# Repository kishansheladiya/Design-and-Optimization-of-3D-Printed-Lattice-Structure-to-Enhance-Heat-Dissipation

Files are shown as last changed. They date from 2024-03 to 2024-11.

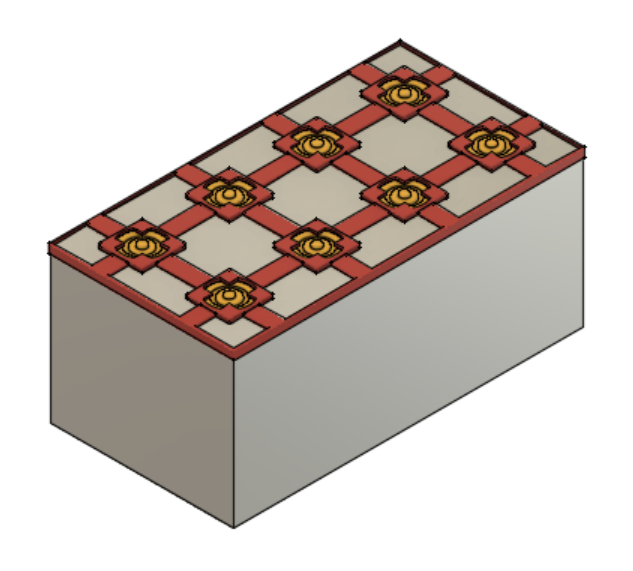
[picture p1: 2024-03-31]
model idea.PNG

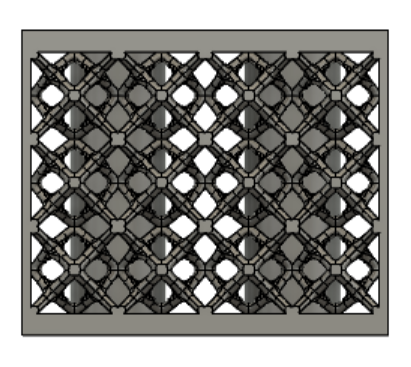
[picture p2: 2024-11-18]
Unitcell/Dedecahedron/front.PNG

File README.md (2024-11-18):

# **Design and Optimization of 3D Printed Lattice Structure to Enhance Heat Dissipation**

This project explores the design and optimization of 3D-printed lattice structures to improve heat dissipation for thermal management applications. Using advanced simulation techniques and CAD modeling, the project demonstrates how lattice geometries can enhance thermal efficiency in various engineering systems.

---

## 📌 **Objectives**
- Design and analyze various lattice structures for enhanced heat transfer.
- Optimize the design to maximize cooling performance while maintaining structural integrity.
- Use additive manufacturing techniques to implement and test designs.

---

## 🔧 **Tools & Technologies Used**
- **Simulation Software**: ANSYS Fluent for thermal analysis.
- **CAD Software**: Fusion 360, Rhino Grasshopper for lattice design.
- **Programming**: Python for data analysis and parameter optimization.

---

## 🛠️ **Methodology**

### **Lattice Design**:
- Designed different lattice structures (e.g., Tricut, BC star tetrahedron) using Rhino Grasshopper and Fusion 360.
- Optimized porosity and surface area for heat transfer performance.

### **Simulation**:
- Conducted structural analysis to ensure load-bearing capability.
- Performed heat transfer simulations using ANSYS Fluent.

### **Optimization**:
- Compared thermal and structural performance of different lattice geometries.

---

## 📊 **Results**

### **Key Findings**:
- Tricut lattice structure exhibited the best cooling performance with a heat transfer value of **1888.80 J/s**.
- Achieved **27% improvement** in heat dissipation compared to baseline designs.

### **Visuals**:
- Example: Temperature contour for Tricut lattice structure.

---

## 🚀 **Applications**
- Battery Thermal Management Systems.
- Heat Sinks and Exchangers.
- Additive Manufacturing for Advanced Cooling Designs.

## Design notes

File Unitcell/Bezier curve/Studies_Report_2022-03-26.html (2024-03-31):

Image Width (pixels):

# Study Report

Analyzed File | bezier curve R 1.2 new result v1
Version | Autodesk Fusion 360 (2.0.12392)
Creation Date | 2022-03-26, 20:36:04
Author | 18BME0245 kishan

#### Project Properties

Title | Studies
Author | K_K_Sheladiya

## Simulation Model 1:1

### Study 1 - Static Stress

##### Study Properties

Study Type | Static Stress
Last Modification Date | 2022-03-26, 17:51:15

#### Settings

##### General

Contact Tolerance | 0.1 mm
Remove Rigid Body Modes | No

##### Damping

##### Mesh

Average Element Size (% of model size)
Solids | 10
Scale Mesh Size Per Part | No
Average Element Size (absolute value) | -
Element Order | Parabolic
Create Curved Mesh Elements | Yes
Max. Turn Angle on Curves (Deg.) | 60
Max. Adjacent Mesh Size Ratio | 1.5
Max. Aspect Ratio | 10
Minimum Element Size (% of average size) | 20

##### Adaptive Mesh Refinement

Number of Refinement Steps | 0
Results Convergence Tolerance (%) | 20
Portion of Elements to Refine (%) | 10
Results for Baseline Accuracy | Von Mises Stress

#### Materials

Component | Material | Safety Factor
Body1 | Aluminum | Yield Strength

##### Aluminum

Density | 2.715E-06 kg / mm^3
Young's Modulus | 71000 MPa
Poisson's Ratio | 0.33
Yield Strength | 85 MPa
Ultimate Tensile Strength | 120 MPa
Thermal Conductivity | 0.222 W / (mm C)
Thermal Expansion Coefficient | 2.4E-05 / C
Specific Heat | 900 J / (kg C)

#### Contacts

#### Mesh

Type | Nodes | Elements
Solids | 706362 | 402637

#### Load Case1

#### Constraints

##### Fixed1

Type | Fixed
Ux | Fixed
Uy | Fixed
Uz | Fixed

###### Selected Entities

For correct interpretation of this image use e.g. IE9, Chrome, Safari, Firefox

#### Loads

##### Force1

Type | Force
Magnitude | 40 N
X Value | 0 N
Y Value | 0 N
Z Value | -40 N
Force Per Entity | No

###### Selected Entities

For correct interpretation of this image use e.g. IE9, Chrome, Safari, Firefox

#### Results

##### Result Summary

Name | Minimum | Maximum
Safety Factor
Safety Factor (Per Body) | 15 | 15
Stress
Von Mises | 2.764E-05 MPa | 0.09797 MPa
1st Principal | -0.04335 MPa | 0.07597 MPa
3rd Principal | -0.1365 MPa | 0.01963 MPa
Normal XX | -0.0581 MPa | 0.06591 MPa
Normal YY | -0.07247 MPa | 0.069 MPa
Normal ZZ | -0.1129 MPa | 0.03409 MPa
Shear XY | -0.02942 MPa | 0.0299 MPa
Shear YZ | -0.03769 MPa | 0.0329 MPa
Shear ZX | -0.03552 MPa | 0.03509 MPa
Displacement
Total | 0 mm | 5.255E-05 mm
X | -1.219E-05 mm | 1.216E-05 mm
Y | -9.805E-06 mm | 9.818E-06 mm
Z | -5.197E-05 mm | 4.024E-07 mm
Reaction Force
Total | 0 N | 0.1304 N
X | -0.04135 N | 0.04227 N
Y | -0.03502 N | 0.03791 N
Z | -0.02533 N | 0.1275 N
Strain
Equivalent | 6.605E-10 | 2.201E-06
1st Principal | -5.492E-08 | 1.462E-06
3rd Principal | -2.404E-06 | 6.831E-09
Normal XX | -5.843E-07 | 8.032E-07
Normal YY | -6.644E-07 | 8.503E-07
Normal ZZ | -1.26E-06 | 3.355E-07
Shear XY | -1.102E-06 | 1.12E-06
Shear YZ | -1.412E-06 | 1.233E-06
Shear ZX | -1.331E-06 | 1.315E-06

##### Safety Factor

###### Safety Factor (Per Body)

0 8

For correct interpretation of this image use e.g. IE9, Chrome, Safari, Firefox

##### Stress

###### Von Mises

[MPa] 0.00003 0.09797

For correct interpretation of this image use e.g. IE9, Chrome, Safari, Firefox

###### 1st Principal

[MPa] -0.04335 0.07597

For correct interpretation of this image use e.g. IE9, Chrome, Safari, Firefox

###### 3rd Principal

[MPa] -0.1365 0.0196

For correct interpretation of this image use e.g. IE9, Chrome, Safari, Firefox

##### Displacement

###### Total

[mm] 0 5.255E-05

For correct interpretation of this image use e.g. IE9, Chrome, Safari, Firefox

Image Width (pixels):

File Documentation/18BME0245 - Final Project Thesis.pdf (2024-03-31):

## DESIGN AND OPTIMIZATION OF 3D PRINTED

## LATTICE STRUCTURE TO ENHANCE HEAT

## DISSIPATION

A PROJECT REPORT

### Submitted in partial fulfillment for the award of the degree of

## Bachelor of Technology

in

## Mechanical Engineering

by

PATEL RUTVIKKUMAR VINAYBHAI - | 18BME0059
SHELADIYA KISHAN KANTIBHAI | - | 18BME0245
SOJITRA DIPTESH MUKESHBHAI | - | 18BME2056

## School of Mechanical Engineering

## April, 2022

DECLARATION BY THE CANDIDATE

### I hereby declare that the project report entitled “DESIGN AND

OPTIMIZATION OF 3D PRINTED LATTICE STRUCTURE TO

### ENHANCE HEAT DISSIPATION” submitted by me to Vellore Institute of

### Technology University, Vellore in partial fulfillment of the requirement for the

award of the degree of Bachelor of Technology in Mechanical Engineering

### is a record of bonafide project work carried out by me under the supervision of

### Prof. Ranjeet Kumar. I declare that this report represents my concepts written

### in my own words and where others' ideas or words have been included, I have

### adequately cited and referenced the original sources. I further declare that I

### have adhered to all principles of academic honesty and integrity and have not

### misrepresented or fabricated or falsified any idea/data/fact/source in my

### submission. I understand that any violation of the above will be cause for

### disciplinary action by the Institute and can also evoke penal action from the

### sources which have thus not been properly cited or from whom proper

### permission has not been taken when needed. Further I affirm that the contents

### of this report have not been submitted and will not be submitted either in part

or in full, for the award of any other degree or diploma and the same is certified.

### Place: Vellore Date: 26/04/2022

SOJITRA DIPTESH MUKESHBHAI

PATEL RUTVIKKUMAR VINAYBHAI | SHELADIYA KISHAN KANTIBHAI

## School of Mechanical Engineering

## BONAFIDE CERTIFICATE

### This is to certify that the project report entitled “DESIGN AND

OPTIMIZATION OF 3D PRINTED LATTICE STRUCTURE TO

ENHANCE HEAT DISSIPATION” submitted by SHELADIYA KISHAN

KANTIBHAI (18BME0245) to Vellore Institute of Technology University,

### Vellore, in partial fulfillment of the requirement for the award of the degree of

Bachelor of Technology in Mechanical Engineering is a record of bonafide

### work carried out by him/her under my guidance. The project fulfills the

### requirements as per the regulations of this institute and in my opinion meets the

### necessary standards for submission. The contents of this report have not been

### submitted and will not be submitted either in part or in full, for the award of

any other degree or diploma and the same is certified.

Project Guide | Head of the Department
Internal Examiner | External Examiner

ACKNOWLEDGEMENT

I express my profound gratitude to my project Guide Dr. Ranjeet Kumar,

Associate Professor Sr Grade 1, School of Mechanical Engineering, VIT,

### enabling me to complete the project thesis, “DESIGN AND OPTIMIZATION

### OF 3D PRINTED LATTICE STRUCTURE TO ENHANCE HEAT

### DISSIPATION”. We would like to thank the School of Mechanical

### Engineering (SMEC), VIT, Vellore for giving me opportunity to Bachelor in

### Mechanical Engineering and Project work. I am greatly thankful to my guide

### Dr. Ranjeet Kumar for his kind support and guidance to successfully complete

### my project work. I have highly benefited by this project work and have gained

### a lot of knowledge about various processes and techniques used in project. I

### would also like to thank our friends who helped us a lot in terms of moral and

technical knowledge.

Place : Vellore

Date : 26/04/2022

SHELADIYA KISHAN KANTIBHAI

TABLE OF CONTENTS

CHAPTER NO. | TITLE | PAGE NO.
| EXECUTIVE SUMMARY | i
| LIST OF TABLES | ii
| LIST OF FIGURES | iii
| LIST OF SYMBOLS AND ABBREVIATIONS | v

1 INTRODUCTION AND LITERATURE REVIEW

| 1.1 Introduction | 1
| 1.2 Project Description | 1
| 1.3 Literature Review & Knowledge gained from it | 2
| 1.4 Gaps in Literature | 7
| 1.5 Objectives of the project | 7

2 METHODOLOGY AND EXPERIMENTAL WORK

| 2.1 Methodology | 8
| 2.2 Unit-cell & Design | 8
| 2.2.1 Parameters | 8
| 2.2.2 Algorithm & Images | 9
| 2.3 CAD Design & Dimensions | 12
| 2.4 Material Selection | 15
| 2.5 Structural Analysis | 16
| 2.6 Heat Transfer Simulation | 19
| 2.6.1 Description and Boundary Conditions | 19
| 2.6.2 Temperature Distribution | 22
| 2.6.3 Heat Transfer Calculation | 25

| 2.6.4 Reynolds Number Calculation | 26
| 2.6.5 Velocity Contours | 27
3 | RESULTS AND DISCUSSION | 28
4 | CONCLUSIONS | 29
| 4.1 Scope for future work | 29
| QUOTATION OF PART MANUFACTURING | 30
| REFERENCES | 31
| PLAGIARISM REPORT | 32
| CONTRIBUTION STATEMENT | 33
| PROGRAMME OUTCOME DATA SHEET | 34

i

EXECUTIVE SUMMARY

Additive manufacturing is expanding its manufacturing capabilities since it is a

futuristic and widely used approach to solve complex design problems. It provides

flexibilities in manufacturing process. This study focuses on heat dissipation. Structured

porous materials show great potential as extended surfaces which is useful in convection

operation. According to previous research, a laminar flow of coolant provides better cooling

capabilities compare to turbulent flow. Therefore, Cooling can be achieved by flowing

coolant into a lattice structure. The aim is to study the behaviour of different lattice structures

in convection and develop optimized lattice structure that gives smooth flow of coolant

which results into better cooling performance. 3D model will be created to understand the

study and various simulation will be done in order to perform optimization of lattice

structures with respect to flow analysis, convection and strength.

ii

LIST OF TABLES

Table No. | Title | Page No.
1 | Parameters of unit cells | 8
2 | Material properties | 15
3 | Material properties of aluminium alloys | 15
4 | Result of stress simulation | 16
5 | Properties of materials which is used in analysis | 19
6 | Boundary condition in simulation | 21
7 | Observed data from ANSYS simulation | 25
8 | Reynolds numbers @Outlet plane | 26
9 | Individual Contribution in the project | 32

iii

LIST OF FIGURES

Figure No. | Title | Page No.
1.1 | Initial battery pack for experiment | 2

1.2

Comparison of convection simulation results on different

shape of fins

3

1.3 | Flow direction in given study | 4

1.4

Portion of the proposed polymer-based battery pack with a

highlighted module that is the building block of the

proposed pack

4

1.5

(a) with a solid insert and a straight channel. (b) with a

lattice insert and curved channels

5

1.6 | Stepwise temperature distributions during the cooling stage | 5

1.7

Photographs of 95% porosity tetrahedral (a) polymer and (b)

metal LFM (c) structure with various porosity

6

2.1 | Porosity Cluster in Grasshopper | 9
2.2 | Grasshopper Algorithm and Unit cell of CSB | 9
2.3 | Grasshopper Algorithm and Unit cell of Dodecahedron | 10
2.4 | Grasshopper Algorithm and Unit cell of BC star tetrahedron | 10
2.5 | Grasshopper Algorithm and Unit cell of Tricut structure | 11
2.6 | Basic CAD design with dimensions | 12
2.7 | CSB lattice structure CAD design | 12
2.8 | Dodecahedron lattice structure CAD design | 13

iv

2.9 | BC star tetrahedron lattice structure CAD design | 13
2.10 | Tricut lattice structure CAD design | 14
2.11 | Load bearing surface during each stress simulation | 16
2.12 | Von mises stress distribution in CSB | 17
2.13 | Von mises stress distribution in Dodecahedron | 17
2.14 | Von mises stress distribution in BC star tetrahedron | 18
2.15 | Von mises stress distribution in Tricut structure | 18
2.16 | Inlet and Outlet during heat transfer study in Ansys Fluent | 20
2.17 | Heat source surface area | 20
2.18 | Fluid domain (left) & Geometry domain(right) | 21
2.19 | Top view of Temp. Contour (CSB) | 22
2.20 | Front view of Temp. Contour (CSB) | 22
2.21 | Top view of Temp. Contour (Dodecahedron) | 23
2.22 | Front view of Temp. Contour (Dodecahedron) | 23
2.23 | Top view of Temp. Contour (BC star tetrahedron) | 23
2.24 | Front view of Temp. Contour (BC star tetrahedron) | 24
2.25 | Top view of Temp. Contour (Tricut structure) | 24
2.26 | Front view of Temp. Contour (Tricut structure) | 24

2.27

Velocity contours a) CSB b) Dodecahedron c) BC star

tetrahedron d) Tricut structures

27

v

LIST OF ABBREVIATIONS

HT | Heat Transfer
AM | Additive Manufacturing
DfAM | Design for Additive Manufacturing
SLS | Selective Laser Sintering
CSB | Centre Symmetry Bezier
U.C. | Unit Cell
Temp. | Temperature

CHAPTER 1

## INTRODUCTION AND LITERATURE REVIEW

### 1.1 INTRODUCTION

Recently, additive manufacturing provides freedom to create complex geometry.

Additive manufacturing is modern method in which a 3D object is created layer by layer

adding materials from digital designs. It is a process that can be useful to achieve various

unusual physical properties including optical, mechanical, electro-magnetic and thermal

properties with artificially designed metamaterials. It can save a lot of materials since it does

not have subtractive methods of manufacturing such as machining process and cutting

process. Even it can save time for preparing process planning, tooling and machining.

Lattice structure is a part of design for additive manufacturing (DfAM). Lattice structure is

included a network of truss including struts or plates interconnected to each other. There are

few kinds of lattice structures including foams, honeycombs and similar constructions.

As many studies shown that enhancement of thermal properties of structures. The aim to

print different type of lattice structure to compare their properties for cooling capabilities.

Based on studies, a thermal metamaterial was designed to act as a thermal insulator as well

as a heat exchanger by enforcing coolant flow through the lattice structure. Cooling capacity

changes with respect to porosity of structure, materials and design of unit-cell. This study

aims to create lattice structure by considering mentioned aspects and more. Optimization of

structure will be done by comparing results which is obtained by changing different

parameters.

### 1.2 PROJECT DESCRIPTION

Nowadays, common cooling method is via convection which is by flowing air or coolant

near to the heat source. For that system needs cooling channel according to source. However,

there are unique ways, which can only be useful because of additive manufacturing as it

gives much more freedom to design complex geometry. By using AM, geometries can be

created with internal cooling channels or designs with lattice structures. Lattice structure can

be useful as path to flow coolant. This study aims to create battery pack with lattice structure

for battery thermal management system. Optimized lattice structure will be identified via

comparing more than one lattice structures.

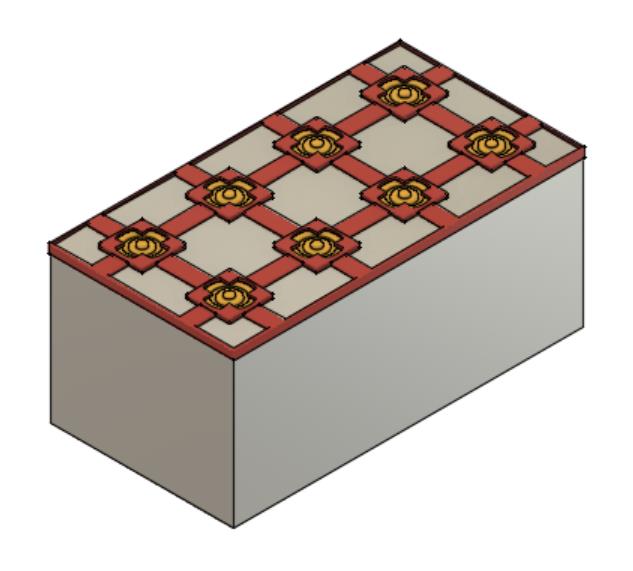
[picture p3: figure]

Figure-1.1 Initial battery pack for experiment

### 1.3 LITERATURE REVIEW & KNOWLEDGE GAINED FROM IT

→ Comparison between the various fin profile using solid works

Fins are mainly used to increases the quantity of heat transfer by improving the rate

of convection heat transfer. Based on the reviewing different research papers, it can observe

that the quantity of heat transferred by the fins is related to the different parameters, which

are height of the fins, angle of the fins and the area covered by the fins.

An increase in the length of the fin or reduce in the spacing between the fins increased

the thermal performance and temperature, decreasing the heat sink's capacity. Fins, when

arranged longitudinally than circular or annular, are much more efficient as it has improved

HT and lower back pressure.

Comparison of different design of fins: -

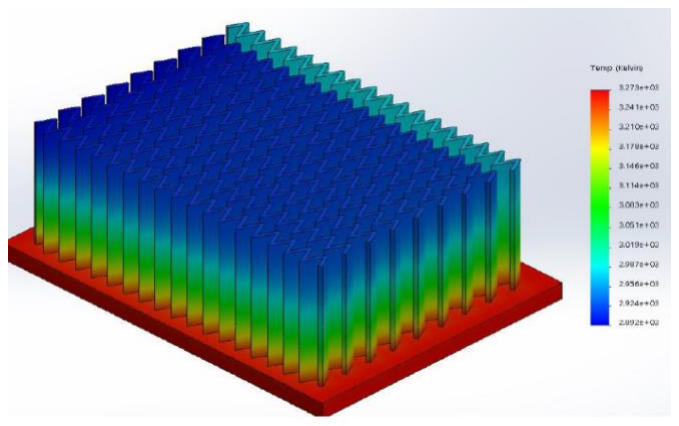
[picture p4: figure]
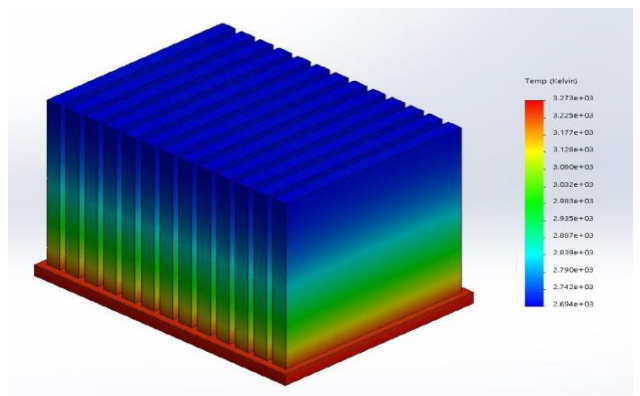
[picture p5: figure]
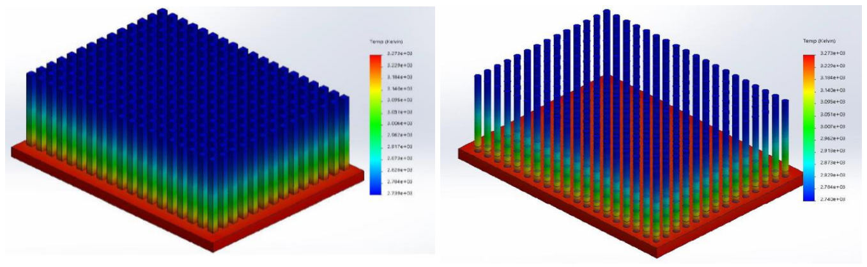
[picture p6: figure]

Figure 1.2 Comparison of convection simulation results on different shape of fins. [1]

The temperature difference is maximum for the plain rectangular fin as it covers more

area. Therefore, the plain rectangular fin has the highest heat transfer. The rectangular pin

fins have a higher transfer in comparison to the cylindrical fins due to the shape as the

rectangular pin fin covers more surface area.

→ Comparison of a lightweight X-type and periodic cellular metallic lattice

Research paper is about a lightweight X-type lattice produced with the metal sheet

folding and presents its thermo-fluidic characteristics in single-phase forced convection. For

fixed porosity, thermal conductivity and Reynolds number, the X-type lattice provides

overall heat removal capacity up to two times higher than reference periodic cellular

materials. The X-type lattice results in a large scale spiral primary flow, which interacts with

several secondary flows. However, the X-type lattice causes roughly three times higher

pressure drop than reference periodic cellular materials for a given Reynolds number.

Overall, superior heat transfer is achieved by the X-type lattice for a fixed pumping

power.

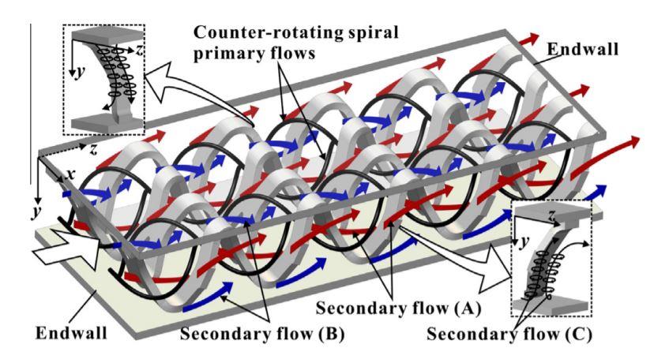
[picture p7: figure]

Figure 1.3 Flow direction in given study. [2]

→ Benefits of 3D printed battery thermal management systems in heat dissipation

The proposed system takes advantage of 3D-printing technology to embedded heat

fins in the cooling channel. Using 3D-printing technology for the manufacture of battery

thermal management systems allows for greater complexity and novelty in the design of the

coolant flow domains, in order to achieve high heat transfer coefficient by the coolant.

Having a high heat transfer coefficient at the coolant side allows the use of lower conductive

materials in the body of the battery pack. The results of this research show that the system

is less sensitive to the flow rate when the coolant inlet temperature is similar to the

environment temperature.

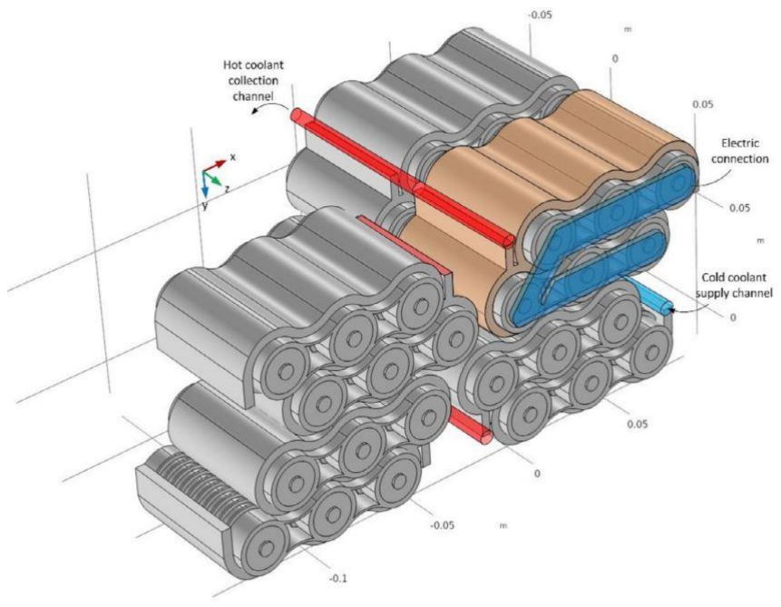
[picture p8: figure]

Figure 1.4 Portion of the proposed polymer-based battery pack with a highlighted module that is

the building block of the proposed pack. [3]

→ Design and additive manufacturing of thermal metamaterial with high thermal

resistance and cooling capability

A lattice-based thermal metamaterial was developed to obtain high thermal

resistance and cooling capability. By insulating the lattice structure. It is possible to obtain

high thermal resistance property. As picture depict, flowing coolant through lattice structure

provide better cooling capabilities compare to simple coolant channels. Result of cooling

experiment: Study shows that lattice structure indicates better cooling as compare to solid.

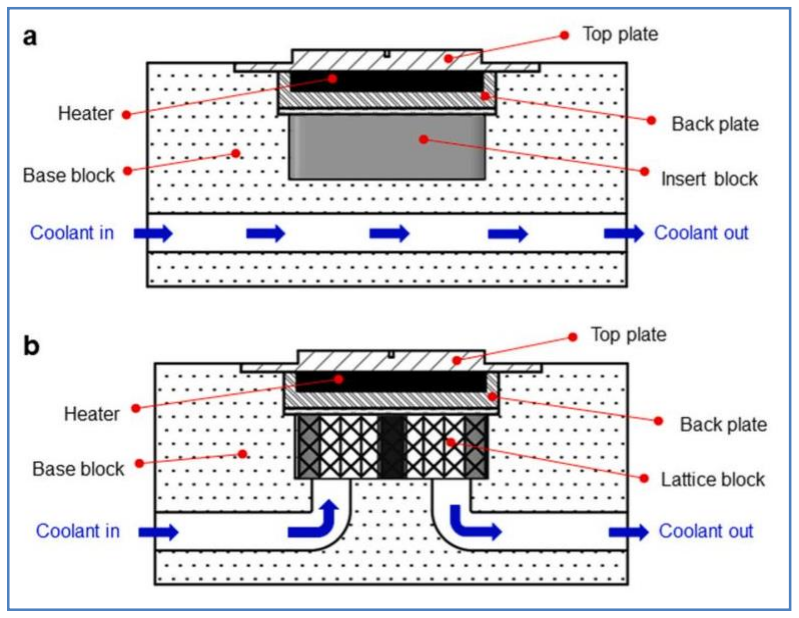
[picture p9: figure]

Figure 1.5 (a) with a solid insert and a straight channel. (b) with a lattice insert and curved

channels.[4]

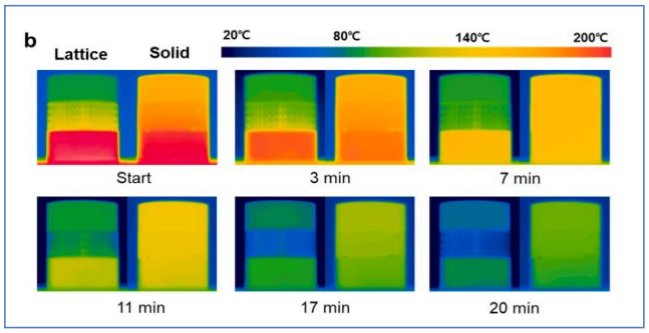
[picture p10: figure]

Figure 1.6 Stepwise temperature distributions during the cooling stage. [4]

→ Structure impact on heat dissipation property:

Structured porous materials show great potential as extended surfaces in heat-exchange

applications which also require design for load-bearing capability.

Some Research indicates that by changing porosity or structural design, highly enhanced

heat dissipation can be achieved. the effect of porosity is studied by changing the ligament

diameter. Past experiments used numerical approach to compare the results. A method was

demonstrated for utilizing the simulation results, which assume perfect surface efficiency,

to predict the performance of LFMs with non-ideal surface efficiency, based on the

conduction resistance of the ligaments.

The result shown that the thermal behavior of the ligaments closely matches that of

cylindrical fins in cross flow and that this analogy can be used to calculate the overall surface

efficiency.

→ Effects of porosity and Coolant flow:

Another research had indicated that surface efficiency is directly proportional to

surface area of the inner structure which intersects with the coolant fluid flow (air flow).

which provides great foundation for enhanced dissipation system.

The research was to observe the effects of fluid flow and porosity on heat liberation

rate. Different porosities (70% to 95%) and fluid flow rate were tested under same

circumstance were tested and the results indicated that the heat dissipation was highest at the

porosity of 95% and it was linearly proportional to the porosity and it varied highly

depending on the coolant flow type.

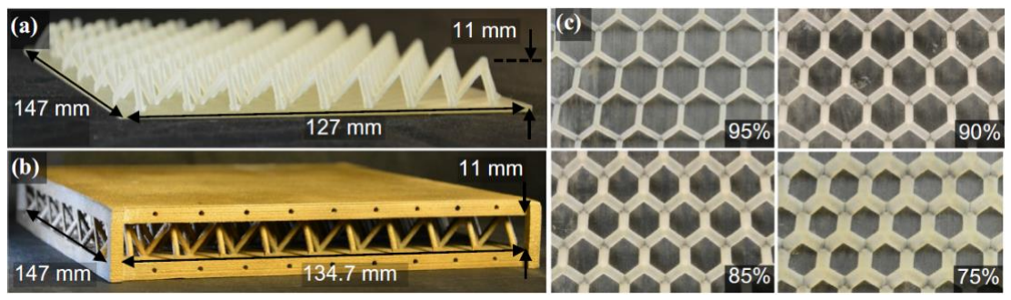
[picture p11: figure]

Figure 1.7 Photographs of 95% porosity tetrahedral (a) polymer and (b) metal LFM samples used for

hydraulic experiments and thermal experiments, respectively; (c) a top-down view of the LFM

structure is shown for the samples of differing porosity used for hydraulic testing. [5]

### 1.4 GAPS IN LITERATURE

- Most of work done so far by only analytical and computational methods. There is

few researches done by experimentation.

- Additive manufacturing can provide freedom to create structure with in-built

channels.

- Cooling capacity depends on porosity and surface area. Additive manufacturing can

allow fabricating with more porosity and surface area within constant volume

compare to conventional method.

### 1.5 OBJECTIVE OF THE PROJECT

Since, many factors are highly dependent on the lattice structure, by considering

these factors, it is possible to create an optimum lattice structure which has all the desired

properties and provides enhanced heat liberation. The objective of this study is to create and

compare a highly porous structure with the balance of high strength and low density and the

air channels should be in such a way that it minimises the flow resistance to maximise the

heat dissipation rate. Computational analysis will be done to perform design optimization.

CHAPTER 2

## METHODOLOGY AND EXPERIMENTAL WORK

### 2.1 METHODOLOGY

- Create unit-cell by using rhino grasshopper software to identify many features such as porosity, and surface area.
- Cad modelling is done with software such as Fusion 360, and Solidworks.
- Material selection with respect to literature review.
- In order to measure and improve strength, we did structural simulation on Fusion360.
- To understand heat transfer analysis, Ansys fluent is used.
- Optimization in design will happened accordingly

### 2.2 UNIT-CELL & DESIGN

### 2.2.1 PARAMETERS

Here, we have created 4 types of unit-cells by Rhino Grasshopper software. Parameters such as porosity, surface area and strut radius are mentioned in table-1.

No. Sr | Name of U.C. | radius Strut | Porosity | Effective surface area (mm² )
1 | Centre Symmetric Bezier | 1.2mm | 83.30 | 315.78
2 | Dodecahedron | 1.2mm | 84.02 | 412.03
3 | BC star tetrahedron | 1.2mm | 85.45 | 435.30
4 | Tricut structure | 1.2mm | 75.98 | 340.41

Table-1. Parameters of unit cells

Centre symmetric: - Initially, 6 points curve was created for

higher accuracy and to find these points, Bezier curve

function is used, where points are (0,0,0), (1,0.633,2),

(2,1.205,4), (3,1.778,6), (4,2.530,8), (5, 5,10). Next, create

a circular array with number of arrays 4 in 360° direction.

Then, multipipe function use to design pipes, which radius

is 1.2 mm. Scale function used in z direction with 0.5

friction value. Lastly, mirror operation was done to create

symmetric in z-axis.

Figure-2.1 Porosity Cluster in Grasshopper

### 2.2.2 ALGORITHM & IMAGES

This section depicts images and algorithms of unit cells which are designed by using rhino grasshopper software.

### - Centre Symmetric Bezier

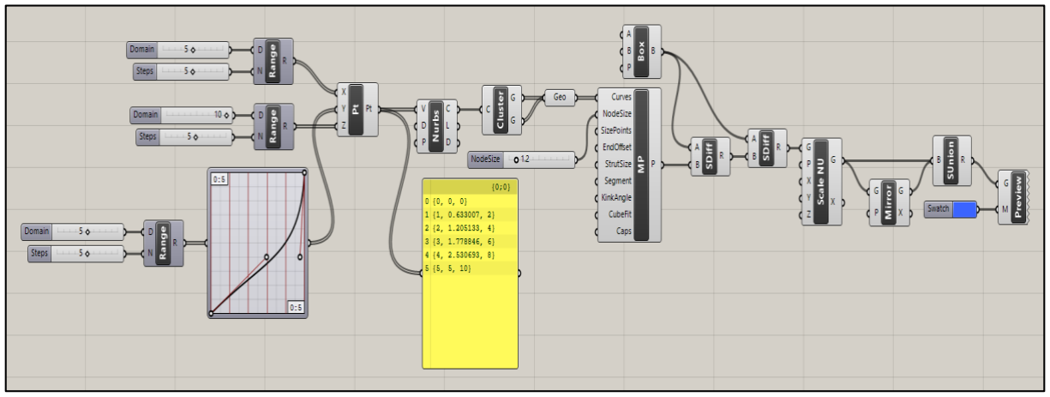
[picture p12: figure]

Figure-2.2 Grasshopper Algorithm and Unit cell of CSB

### - Dodecahedron

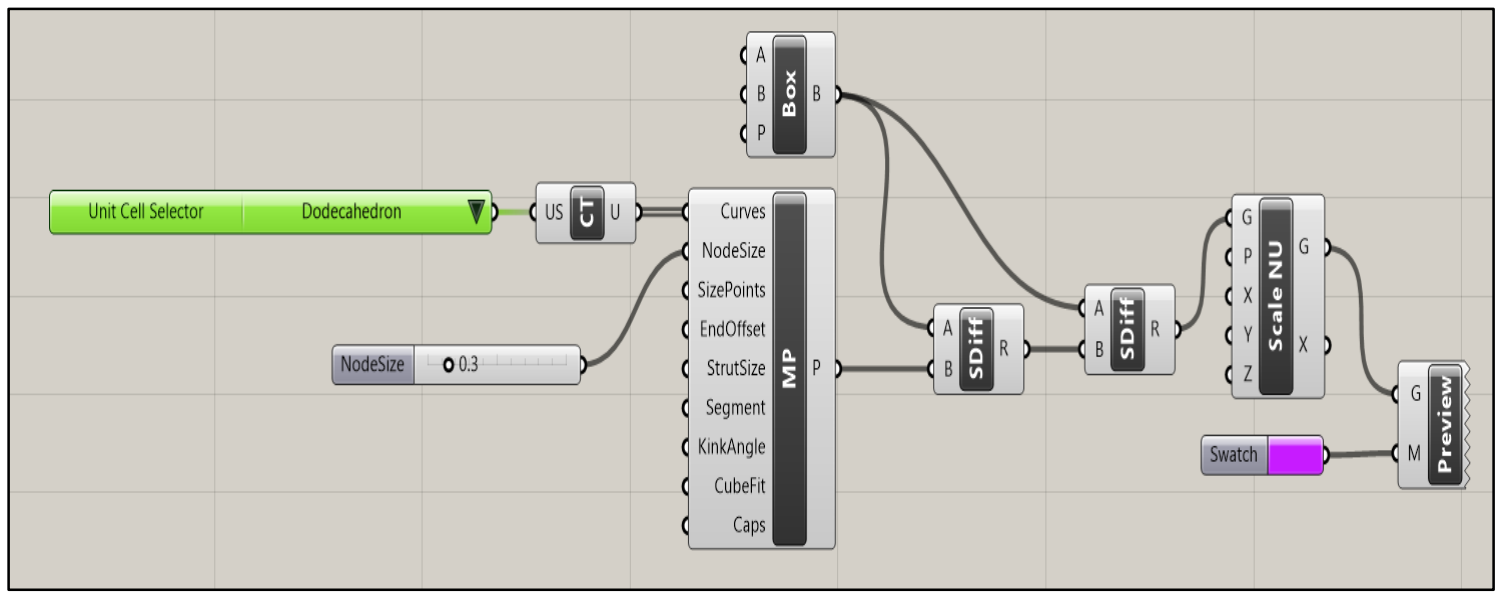
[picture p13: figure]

Figure-2.3 Grasshopper Algorithm and Unit cell of Dodecahedron

### - BC star tetrahedron

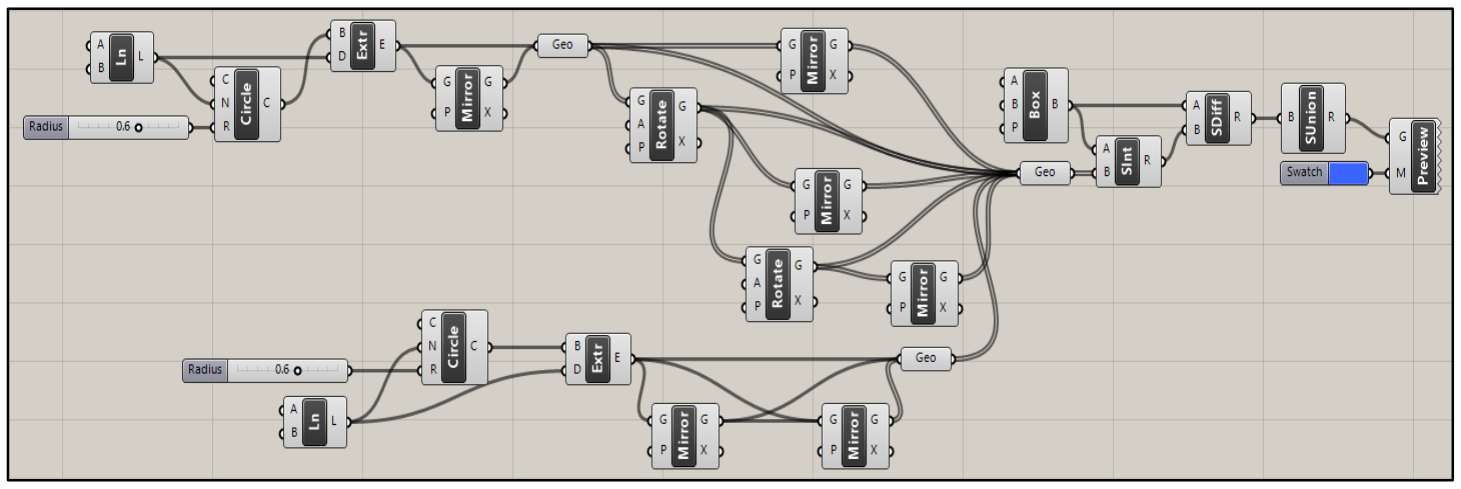
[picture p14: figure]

Figure-2.4 Grasshopper Algorithm and Unit cell of BC star tetrahedron

Dodecahedron: - To begin with, in grasshopper, feature of

unit-cell was used to create all curves of this cell.

Afterwards, with the help of multipipe function, all pipes

were made, where its radius was set as 1.2 mm.

BC star tetrahedron: - At starting point, two diagonal lines

were created in face and body of the cube each. Then circle

with 1.2 mm radius extrude in direction of line for both

lines. Consequently, with the help of mirror and rotate

tools, all the faces and body diagonals were created in cube.

### - Tricut structure

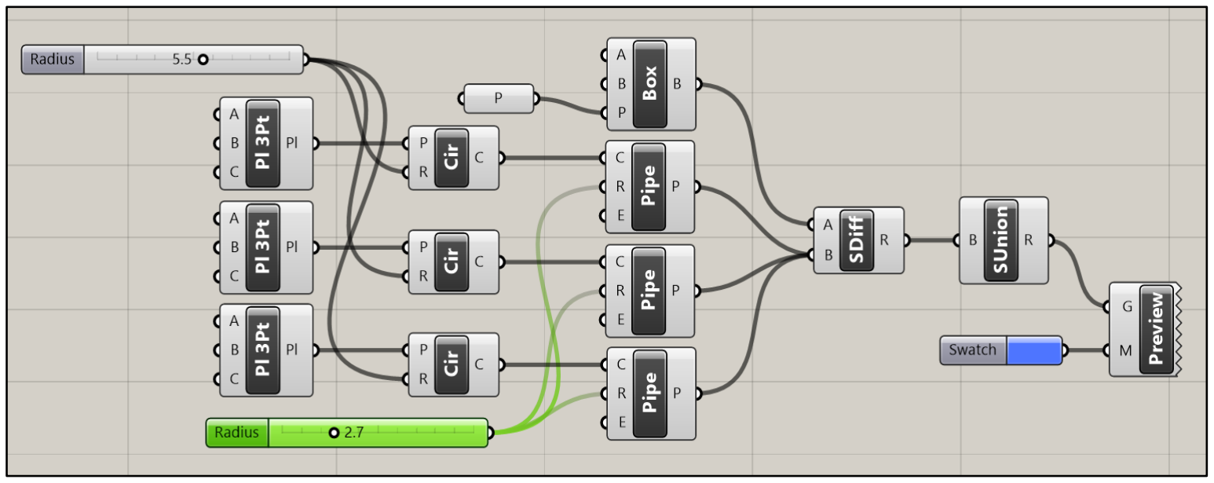
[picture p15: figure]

Figure-2.5 Grasshopper Algorithm and Unit cell of Tricut structure

Tricut structure: - At first, 3 circular pipes were

created in all three plans XY, YZ, ZX. Subsequently, it was extruded as a cut from 1cm³
box.

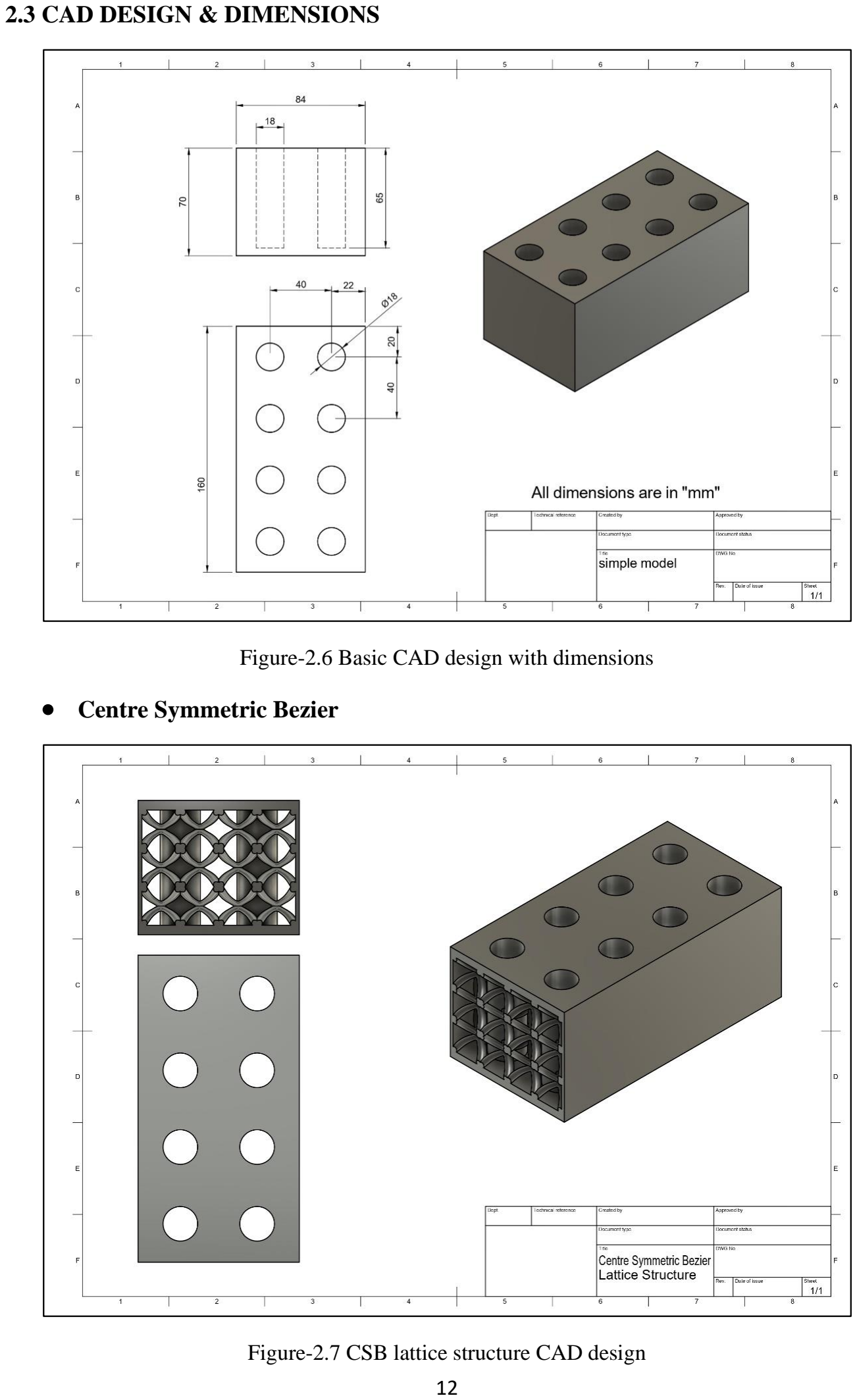
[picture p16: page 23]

### 2.3 CAD DESIGN & DIMENSIONS

Figure-2.6 Basic CAD design with dimensions

- Centre Symmetric Bezier

Figure-2.7 CSB lattice structure CAD design

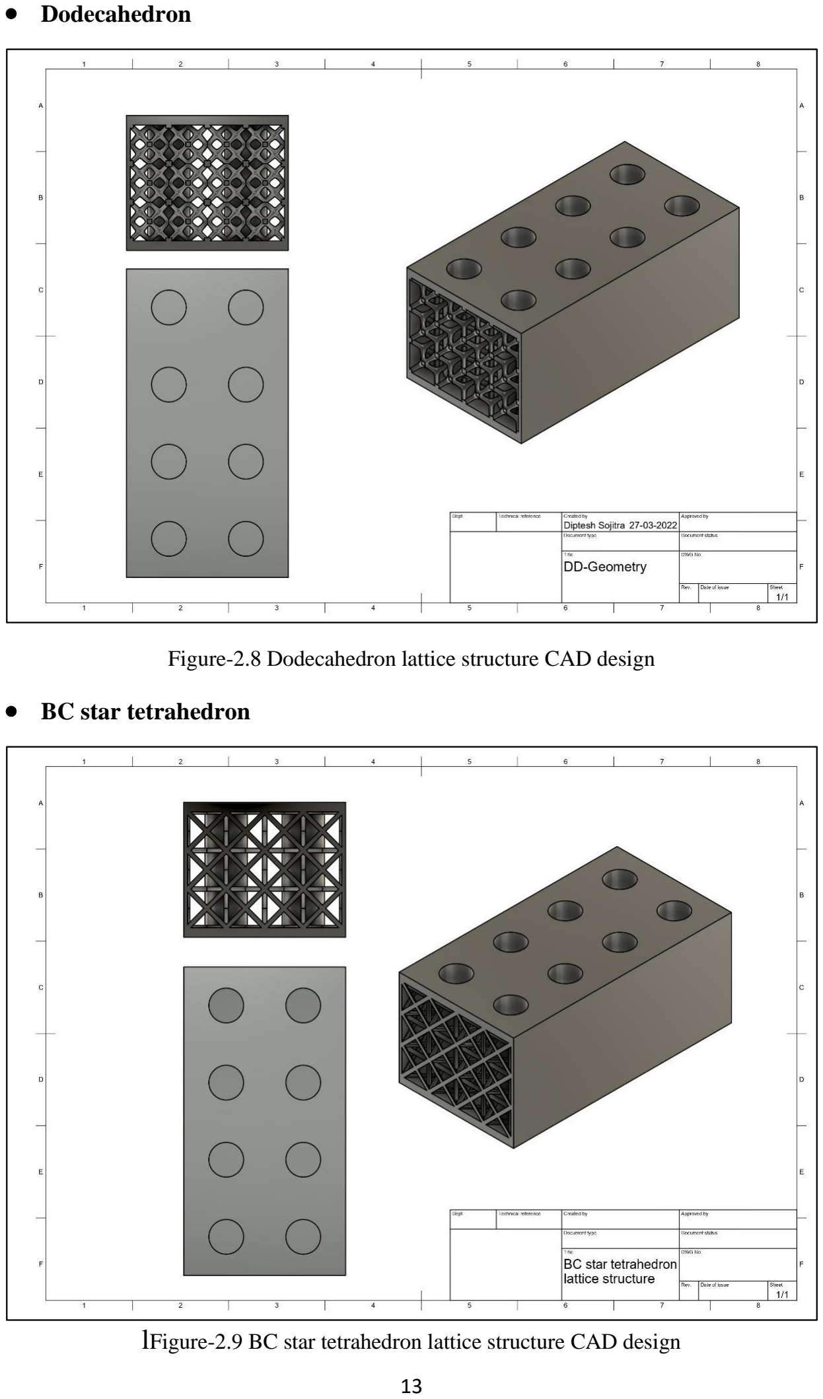
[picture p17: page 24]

- Dodecahedron

Figure-2.8 Dodecahedron lattice structure CAD design

- BC star tetrahedron

lFigure-2.9 BC star tetrahedron lattice structure CAD design

- Tricut structure

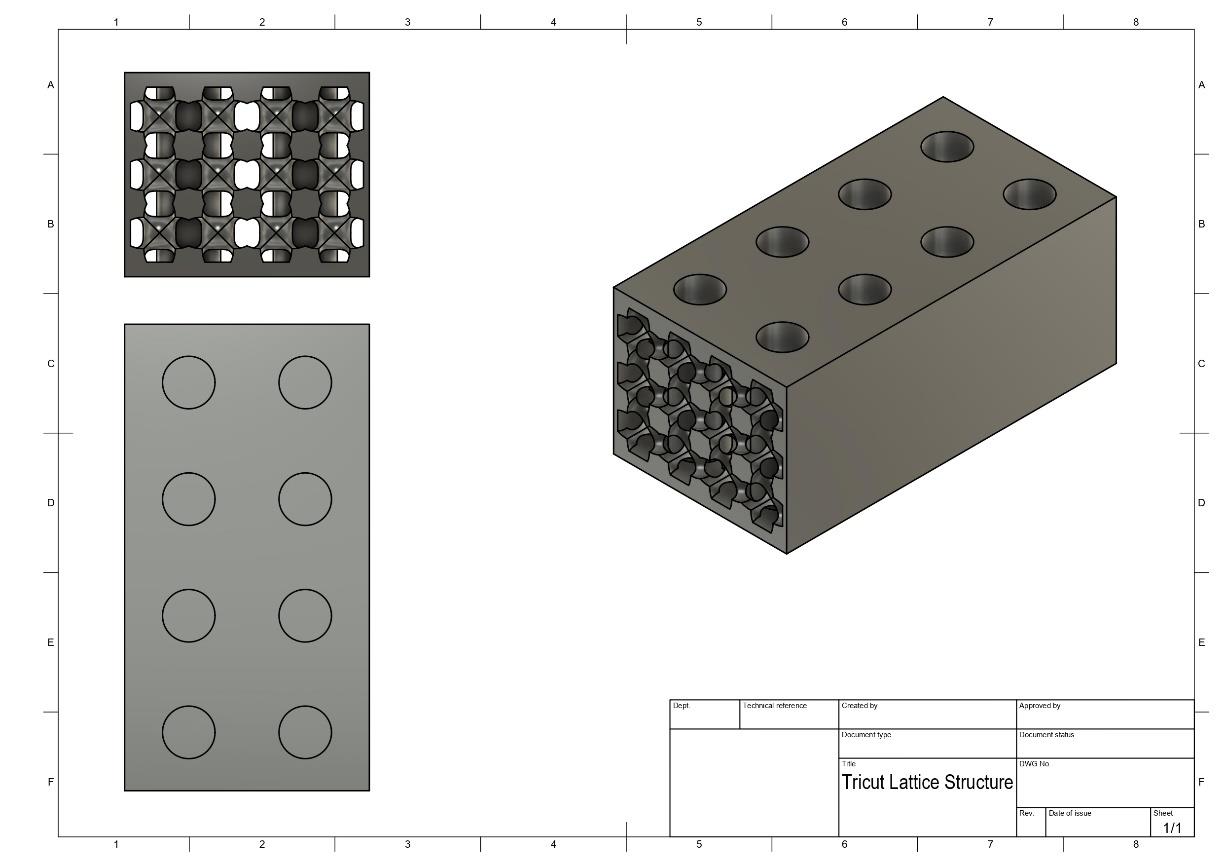
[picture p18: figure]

Figure-2.10 Tricut lattice structure CAD design

### 2.4 MATERIAL SELECTION

Nowadays, majority of metal 3D printing is manufactured using Selective Laser Sintering

(SLS). Plenty of materials namely Stainless steel, Tool steel, Titanium, Inconel 625, Cast

iron, Nickel, Cobalt, Aluminium, are most compatible in SLS. Among these materials,

aluminium has highest heat co-efficient which more suitable factor for our study. As

aluminium has several alloys from which aluminium-1050 has highest heat co-efficient (229

W/ m K).

SR NO. Material | Heat Coefficient (W / m K) Young's Modulus (GPa)
1 | Stainless Steel | 25 | 190
2 | Tool Steel | 65 | 210
3 | Titanium | 17 | 106
4 | Inconel 625 | 15 | 205.8
5 | Iron (Cast) | 55 | 41
6 | Nickel | 92 | 207
7 | Cobalt | 69 | 205
8 | Aluminium (1050) 222 | 71
| | Table-2. Material properties
Sr. No | Aluminium alloy | Thermal Conductivity (W / m K)
1 | 1050 | 222
2 | 6060 | 166
3 | 6061 | 152
4 | 6063 | 201

Table-3. Material properties of aluminium alloys

### 2.5 STRUCTURAL ANALYSIS

This stress analysis is done on each geometry by applying 40N force distribution on upper

face as shown in figure-12. As lattice structure is significant factor for heat dissipation so

that it is important to assure that structure does not deforms under normal load condition.

Resultant data of structural analysis is given in the table.4 and stress distribution amongst all

four-design mentioned from figure-13 to figure-16.

Sr No. | Name of U.C. | Stress (MPa) | Strain | Displacement (mm)
1 | Centre Symmetric Bezier | 0.09797 | 2.201 x 10⁻⁶ | 5.255 x 10⁻⁵
2 | Dodecahedron | 0.1409 | 3.444 x 10⁻⁶ | 4.427 x 10⁻⁵
3 | BC star tetrahedron | 0.1045 | 2.406 x 10⁻⁶ | 3.782 x 10⁻⁵
4 | Tricut structure | 0.1134 | 2.442 x 10⁻⁶ | 3.043 x 10⁻⁵

Table-4. Result of stress simulation

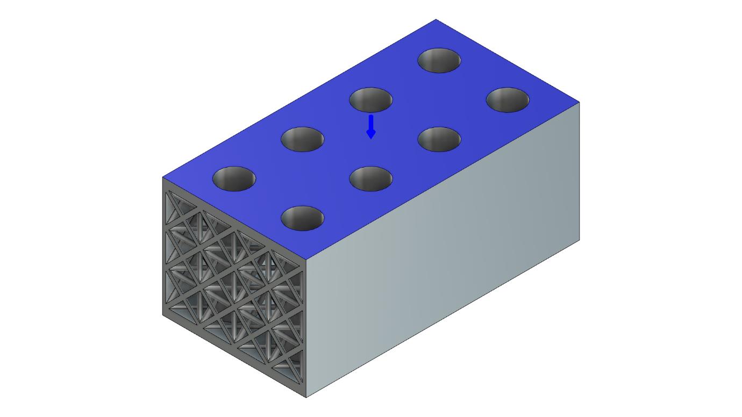
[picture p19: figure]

Figure-2.11 Load bearing surface during each stress simulation

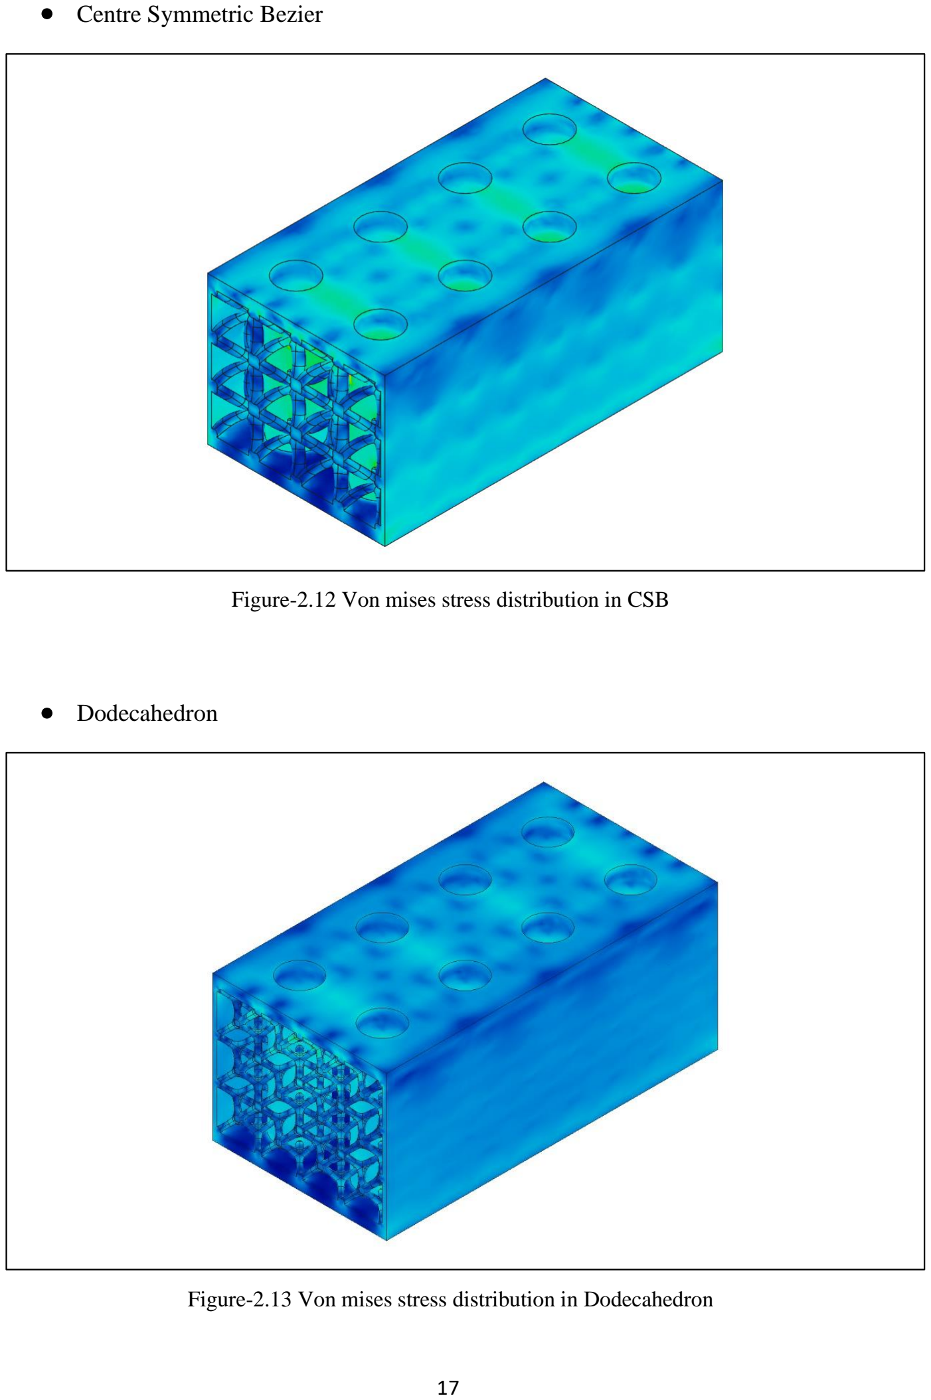
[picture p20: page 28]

- Centre Symmetric Bezier

Figure-2.12 Von mises stress distribution in CSB

- Dodecahedron

Figure-2.13 Von mises stress distribution in Dodecahedron

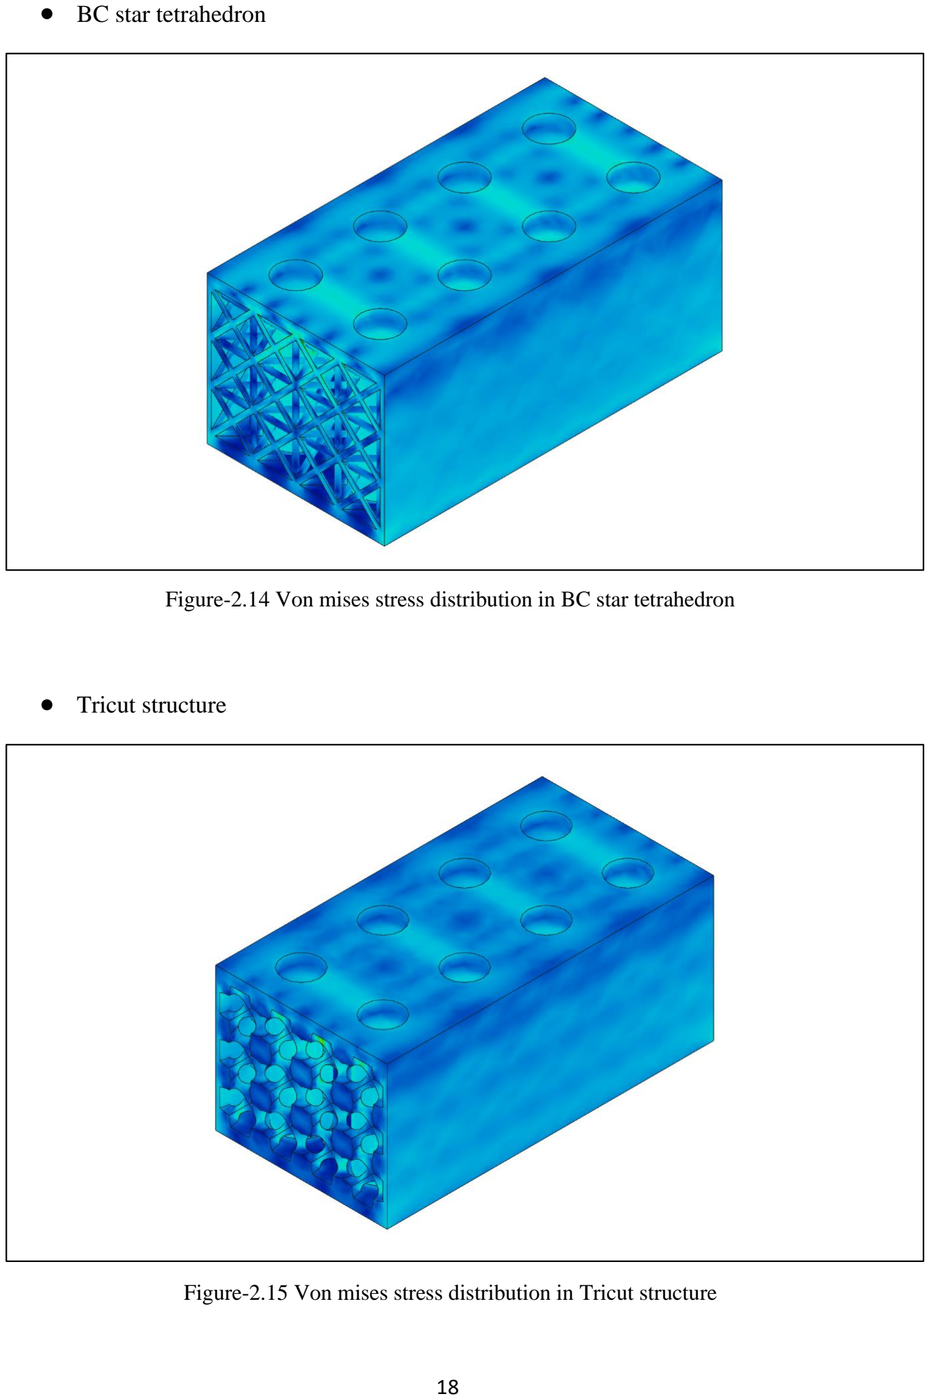
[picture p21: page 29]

- BC star tetrahedron

Figure-2.14 Von mises stress distribution in BC star tetrahedron

- Tricut structure

Figure-2.15 Von mises stress distribution in Tricut structure

### 2.6 HEAT TRANSFER SIMULATION

### 2.6.1 DESCRIPTION AND BOUNDARY CONDITIONS

This study of heat transfer is done with ANSYS fluent to find temperature distribution

and heat transfer rate through the various geometry which is mentioned in geometry

section. There is total four structures with different internal lattice structures. We are

comparing various design. Therefore, to achieve fair comparison in this study, boundary

condition and physical properties should be equal during analysis. Figure.17 below

shows inlet and outlet in geometry during analysis. In this study, Air is used as coolant

which passes through the geometry. Furthermore, Aluminium-1050 is assigned as

material to geometry during all four studies. Figure.19 illustrate both fluid and geometry

domain. Here, hot surfaces which act as heat sources during studies are mentioned in

Figure.18 Properties of both material which is used in studies mentioned in below

table.5. All boundary conditions,such as inlet velocity of air, outlet pressure, temperature

of hot surfaces, are indicated in table.6.

Material | Thermal conductivity (W/ m k) | Density (kg/m³

)

| | | Specific heat (J/ kg K)
Air | 0.0242 | 1.225 | 1006.4

Aluminium-

1050 | 222 | 2710 | 871

Table.5 - Properties of materials which is used in analysis

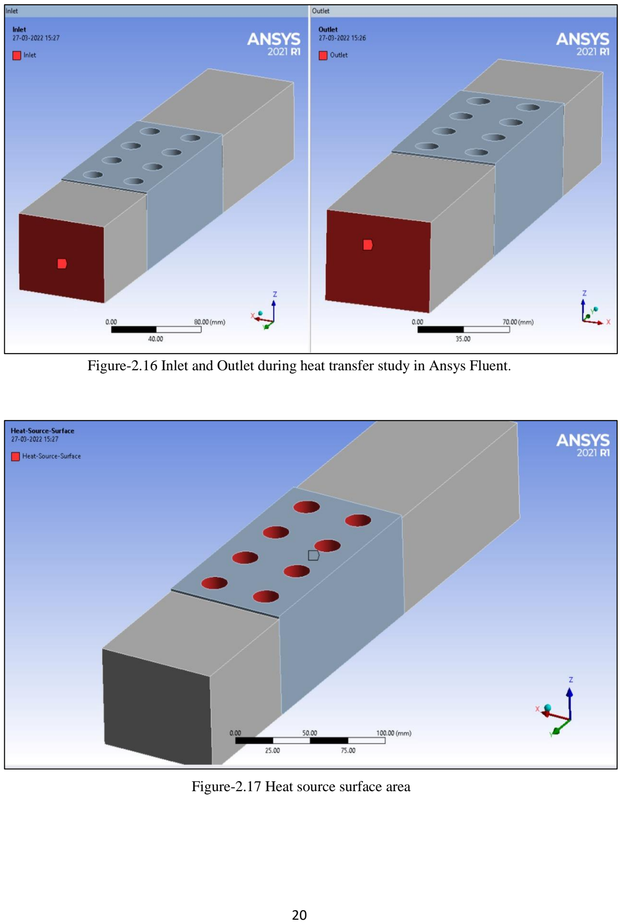
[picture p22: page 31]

Figure-2.16 Inlet and Outlet during heat transfer study in Ansys Fluent.

Figure-2.17 Heat source surface area

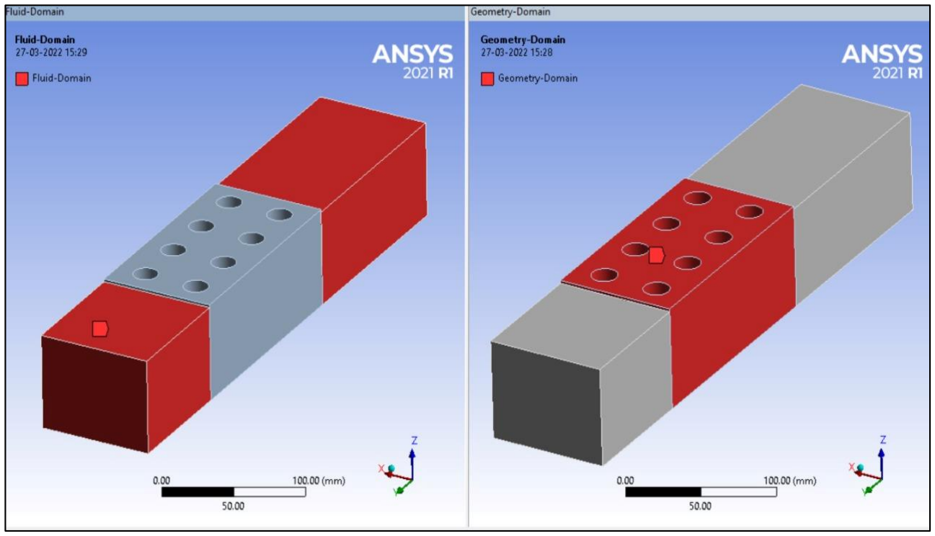
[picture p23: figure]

Figure-2.18 Fluid domain (left) & Geometry domain (right)

Boundary | Value | Type
Inlet | 15m/s @300K | Velocity-inlet
Outlet | Atmospheric pressure (1.013 bar) | Pressure-outlet
Hot surface (Heat source) | 343K | Wall

Table.6 - Boundary condition in simulation

In general, lithium-ion batteries can be charged in an environment up to 45°C and discharged in temperatures as high as 75oC. According to given data, heat transfer study

is proposed at 70 oC for analysis. Inlet velocity is taken as 54kmph (15 m/s) @ 300K

which is average vehicle speed with ambient temperature.

### 2.6.2 TEMPERATURE DISTRIBUTION

Here, temperature distribution contours are represented from Figure.20 to Figure.27. These

contours are showing temperature distribution at middle plane in geometry in top (XY) &

right (YZ) planes.

- Centre Symmetric Bezier (CSB):

Figure-2.19 Top view of Temp. Contour (CSB)

Figure-2.20 Front view of Temp. Contour (CSB)

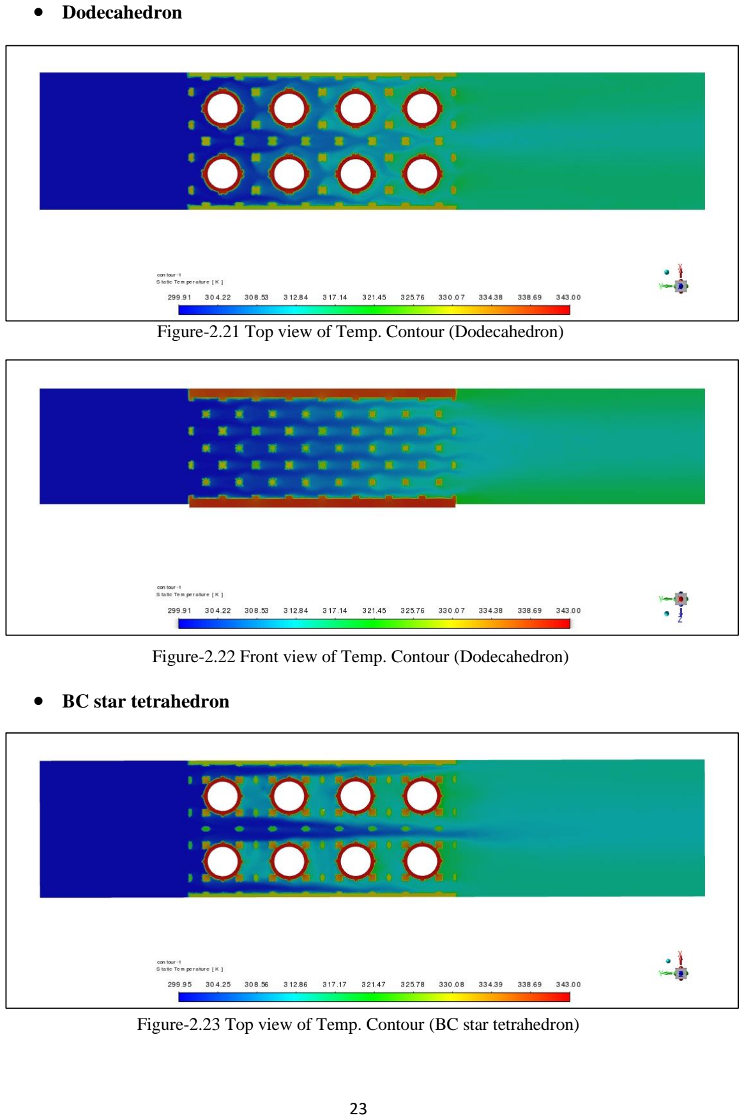
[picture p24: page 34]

- Dodecahedron

Figure-2.21 Top view of Temp. Contour (Dodecahedron)

Figure-2.22 Front view of Temp. Contour (Dodecahedron)

- BC star tetrahedron

Figure-2.23 Top view of Temp. Contour (BC star tetrahedron)

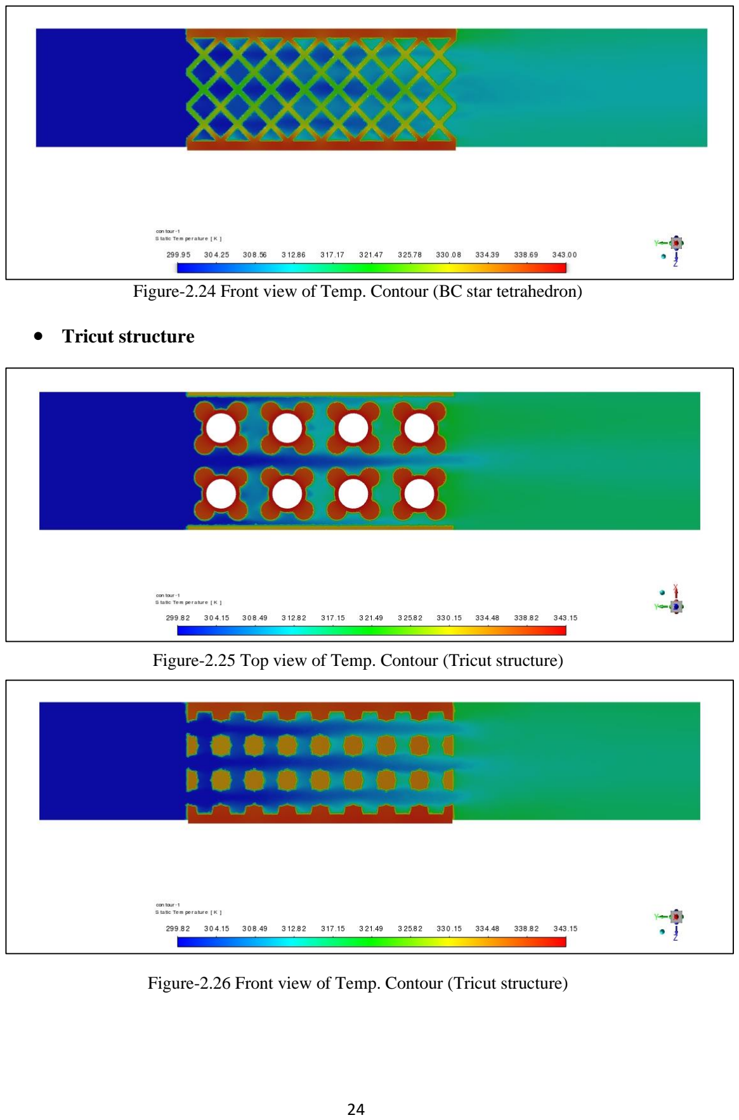
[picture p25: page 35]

Figure-2.24 Front view of Temp. Contour (BC star tetrahedron)

- Tricut structure

Figure-2.25 Top view of Temp. Contour (Tricut structure)

Figure-2.26 Front view of Temp. Contour (Tricut structure)

### 2.6.3 HEAT TRANSFER CALCULATION

For these studies, it is assumed that entire system is thermally isolated. Coolant air is passing

in Y-direction through the structures with initial temperature of 300K at inlet. For outlet

temperature, we have taken average temperature at outlet plane. As per energy conversation

law, heat dissipated by structure is equivalent to the heat gain by the air in this system which

can be calculated by the given formula;

## Q=ṁ×c×ΔT

ṁ = mass flow rate (kg/s)

c = specific heat capacity (J / kg. K)

ΔT = temperature difference between outlet and inlet (K)

From all four analysis, inlet and outlet temperatures are obtained that is described in

table.7.

SR No. | Name | Inlet Temp. (K) | Outlet Temp. (K) | Heat Transfer (J/s)
1 | Centre Symmetric Bezier | 300 | 314.3 | 1487.09
2 | Dodecahedron | 300 | 317.25 | 1795.20
3 | BC star tetrahedron | 300 | 315.45 | 1627.76
4 | Tricut structure | 300 | 318.17 | 1888.80

Table.7 – Observed data from ANSYS simulation

### 2.6.4 REYNOLDS NUMBER CALCULATION

ρ = Fluid density = 1.225 kg/m³

V = Fluid velocity (m/s)

μ = Fluid viscosity (kg/ m. s)

L = characteristic linear dimension = 4*(Area)/(Perimeter) = 75.15 x 10⁻³ m

SR No. | Name | Velocity(m/s) @Outlet plane | Reynolds Number @Outlet plane
1 | Centre Symmetric Bezier | 19.15 | 98520
2 | Dodecahedron | 18.86 | 97028
3 | BC star tetrahedron | 19.21 | 98829
4 | Tricut structure | 22.99 | 118275

Table.8 – Reynolds numbers @Outlet plane

### 2.6.5 VELOCITY CONTOURS

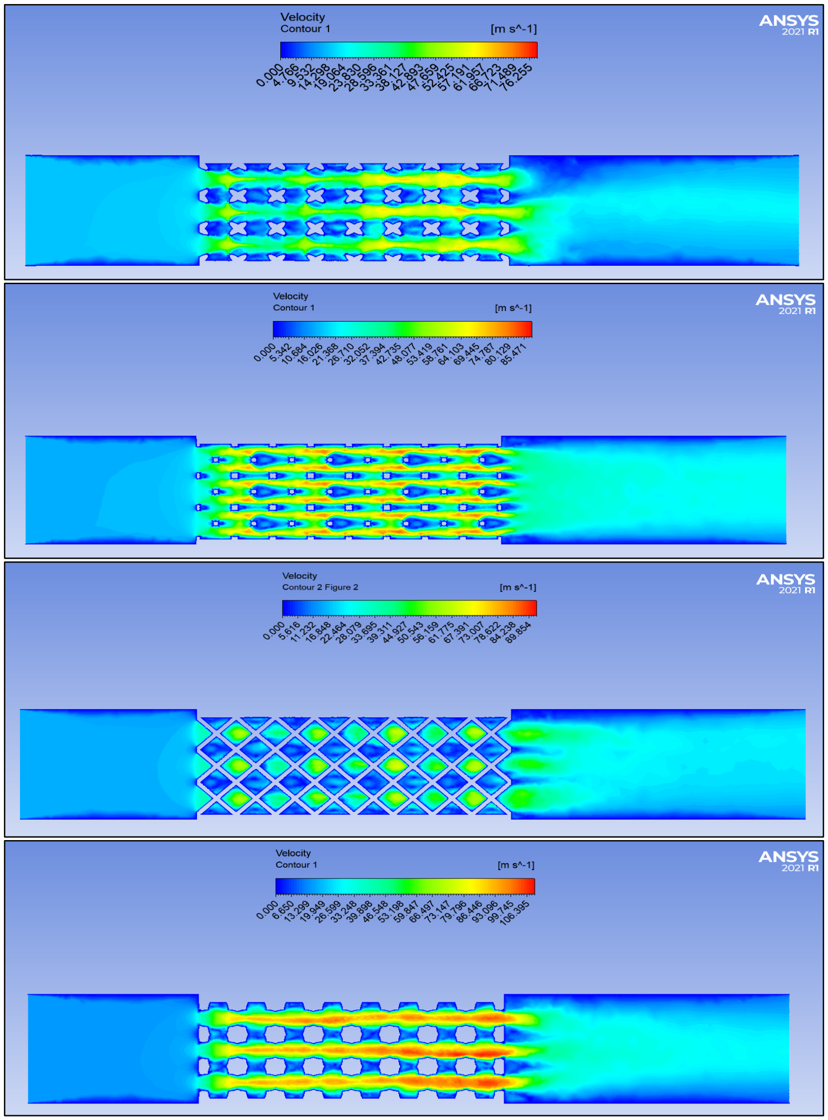
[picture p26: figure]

Figure-2.27 Velocity contours a) CSB b) Dodecahedron c) BC star tetrahedron d) Tricut structures

CHAPTER 3

## RESULTS AND DISCUSSION

After carefully studying simulation data and results, it depicts that Tricut lattice structure has

Higher heat transfer value compared to others. The outlet temperature is observed at value

of 318.17K. The heat transfer value of this structure obtained which is 1888.80 J/s. The heat

transfer amount of Tricut structure is 27.01%, 5.21% and 16.03% higher than CSB,

Dodecahedron and BC star tetrahedron respectively. Additionally, Tricut lattice structure

show better heat transfer compare to CSB because it has higher effective surface area. While

having low porosity and effective surface area compare to BC star tetrahedron and

Dodecahedron, Tricut shows better heat transfer because it has smooth and less obstacles

path for fluid to pass which leads to less turbulent. Under turbulent flow conditions, the

increase in heat transfer rate is more significant than that under laminar flow conditions [8].

The turbulent effects become a dominant factor over secondary flow at higher Reynolds

number. Therefore, with maximum turbulence, Tricut structure achieves highest heat

transfer compare to others.

CHAPTER 4

## CONCLUSIONS

In conclusion, there are four type of lattice geometry created by using rhino grasshopper and

Fusion 360 followed by stress simulation which is done by also Fusion 360 software. While

we have used Ansys mechanical and fluent for the operations like pre-processing, meshing,

and post processing of heat transfer simulation. There are four types of lattice structures have

been used for analysis study namely Centre Symmetric Bezier, Dodecahedron, BC star

tetrahedron and Tricut structure. Among them, simulations depict that tricut structure has

better heat dissipation compare to others with following reasons such as higher turbulence,

better surface area and porosity.

### 4.1 SCOPE FOR FUTURE WORK

This study will be helpful to get insight of heat dissipation through the lattice geometry and

may lead towards innovative solution for cooling problems. As additive manufacturing is

providing freedom of design and there are so many various types of lattice structure. To

perform on analysis and experimental work on lattice structure can be helpful to achieve

optimum lattice for better heat dissipation according to its applications. Area of applications

like battery management system, Heat sink, Heat exchanger, where this type of solution may

bring better performance.

QUOTATION OF PART MANUFACTURING

REFERENCES

[1]Vaishnav madhavadas, Dilyarup das, kaustubh anand mohta, s. Senthur. Comparative

analysis on heat transfer of variousfin profile using solid works: A systematic review. School

of Mechanical Engineering, Vellore Institute of Technology (VIT), India; 2021. Earth

Environ. Sci. 850 012029.

[2]H.B. Yan, q.C. Zhang, t.J. Lu, t. Kim. A lightweight x-type metallic lattice in single-

phase forced convection. School of Energy and Power Engineering, Xi’an Jiaotong

University, China; 2014.

[3]Maan Al-Zareer. Numerical Study of Flow and Heat Transfer Performance of 3D-Printed

Polymer-Based Battery Thermal Management. Department of Mechanical and Industrial

Engineering, University of Toronto, Canada; 2020.

[4]Jeong-Hee You, Keun Park. Design and additive manufacturing of thermal metamaterial

with high thermal resistance and cooling capability. Department of Mechanical System

Design Engineering, Seoul National University of Science and Technology, Republic of

Korea; may 2021.

[5]Karen N. Son, Justin A. Weibel, Vellaisamy Kumaresan, Suresh V. Garimella. Design of

multifunctional lattice-frame materials for compact heat exchangers. School of Mechanical

Engineering, Purdue University, USA; 2017.

[6]Xin Jin, Beibei Shen, Hongbin Yan, Bengt Sunden, Gongnan Xie. Comparative

evaluations of thermofluidic characteristics of sandwich panels with X-lattice and

Pyramidal-lattice cores. School of Mechanical Engineering, Northwestern Polytechnical

University, Shaanxi, China; December 2018.

[7] Akihiro Takezawa, Xiaopeng Zhang, Mitsuru Kitamura. Optimization of an additively

manufactured functionally graded lattice structure with liquid cooling considering structural

performances. Graduate school of Engineering, Hiroshima University, Japan; November

2019.

[8] Pranit M. Patil, Amol P. Yadav, Dr. P. A. Patil, Comparative Study between Heat

Transfer through Laminar Flow and Turbulent Flow; Vol. 4, Issue 4, April 2015

32

PLAGIARISM REPORT

33

34

CONTRIBUTION STATEMENT

Individual Contribution | Rutvik (18BME0059) | Kishan (18BME0245) | Diptesh (18BME2056)
Literature Review | 🗸 | 🗸 | 🗸
Design (Rhino & Fusion 360) | - | 🗸 | 🗸
Material Selection | 🗸 | - | -
Structural Analysis (Fusion 360) | 🗸 | 🗸 | -
Heat Transfer Analysis (Ansys Fluent) | - | - | 🗸
Final Documentation | 🗸 | 🗸 | 🗸

Table.9 – Individual Contribution in the project

Verified by

(Signature of the Guide)

35

PROGRAMME OUTCOMES ATTAINED

Programme Outcomes | Attainment Level
PO_1: Engineering Knowledge: Apply the knowledge of mathematics, science, engineering fundamentals, and an engineering specialization to the solution of complex engineering problems. | LOW
PO_2: Problem Analysis: Identity, formulate, review research literature, and analyse complex engineering problems reaching substantiated conclusions using first principles of mathematics, natural sciences, and engineering sciences. | HIGH
PO_3: Design/Development of Solutions: Design solutions for complex engineering problems and design system components or processes that meet the specified needs with appropriate consideration for public health and safety, and cultural, societal, and environmental considerations. | NA
PO_4: Conduct Investigations of Complex Problems: Use research-based knowledge and research methods including design of experiments, analysis, and interpretation of data, and synthesis of the information to provide valid conclusions for complex problems | HIGH
PO_5: Modern Tool Usage: Create, select, and apply appropriate techniques, resources, and modern engineering and IT tools including prediction and modeling to complex engineering activities with an understanding of the limitations. | HIGH
PO_6: The Engineer and Society: Apply reasoning informed by the contextual knowledge to assess societal, health, safety, legal and cultural issues and the consequent responsibilities relevant to the professional engineering practice. | NA

36

PO_7: Environment and Sustainability: Understand the impact of the professional engineering solutions in societal and environmental contexts, and demonstrate the knowledge of, and need for sustainable development. | NA
PO_8: Ethics: Apply ethical principles and commit to professional ethics and responsibilities and norms of the engineering practice. | MEDIUM
PO_9: Individual and Teamwork: Function effectively as an individual, and as a member or leader in diverse teams, and in multidisciplinary settings. | HIGH
PO_10: Communication: Communicate effectively on complex engineering activities with the engineering community and with society at large, such as, being able to comprehend and write effective reports and design documentation, make effective presentations, and give and receive clear instructions. | HIGH
PO_11: Project Management and Finance: Demonstrate knowledge and understanding of the engineering and management principles and apply these to one’s own work, as a member and leader in a team, to manage projects and in multidisciplinary environments. | NA
PO_12: Life-long Learning: Recognize the need for and have the preparation and ability to engage in independent and lifelong learning in the broadest context of technological change. | NA

Verified by

(Signature of the Guide)

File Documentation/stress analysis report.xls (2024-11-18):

 | case study | center symetric | 3 side cut | dodecahedron | BC star tetrahedron
Displacement (mm) | vertical force of 40N | 5.255 E-05 | 3.043 E-05 | 4.427 E-05 | 3.782 E-05
Stress | vertical force of 40N | 0.09797 | 0.1134 | 0.1409 | 0.1045
Strain | vertical force of 40N | 2.201 E-06 | 2.442 E-06 | 3.444 E-06 | 2.406 E-06
FOS | vertical force of 40N | 15 | 15 | 15 | 15

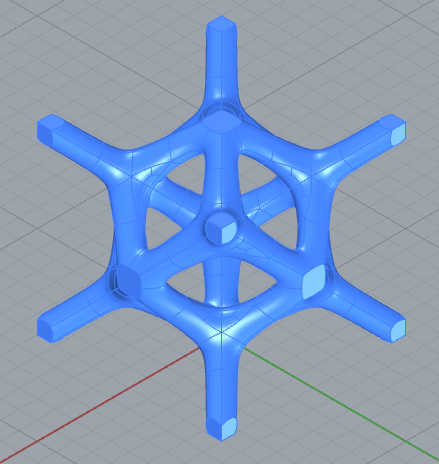
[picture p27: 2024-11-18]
Unitcell/Dedecahedron/unit cell view.PNG

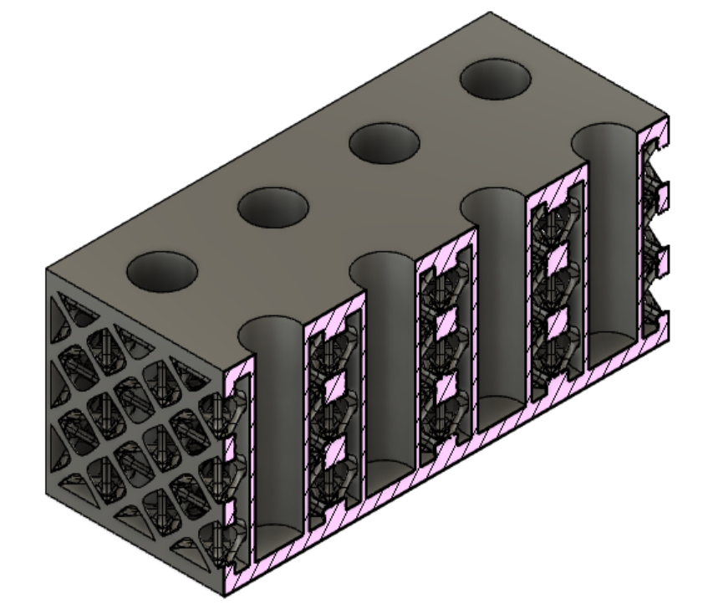
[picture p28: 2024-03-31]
Unitcell/BC star tetrahedron/section.PNG

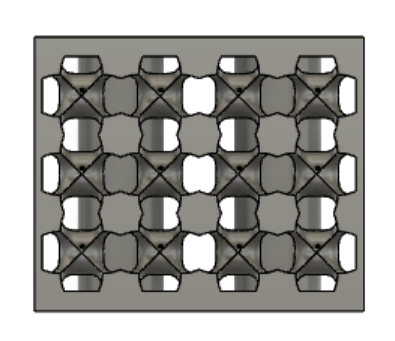
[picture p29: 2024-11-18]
Unitcell/Tricut structure/front.PNG

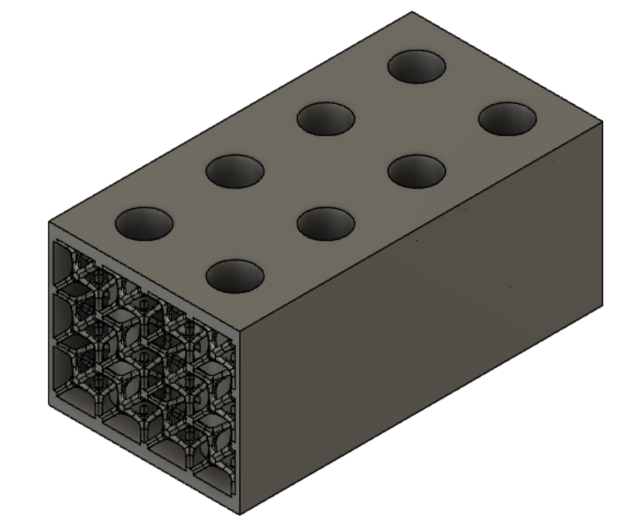
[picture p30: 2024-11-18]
Unitcell/Dedecahedron/isometric.PNG

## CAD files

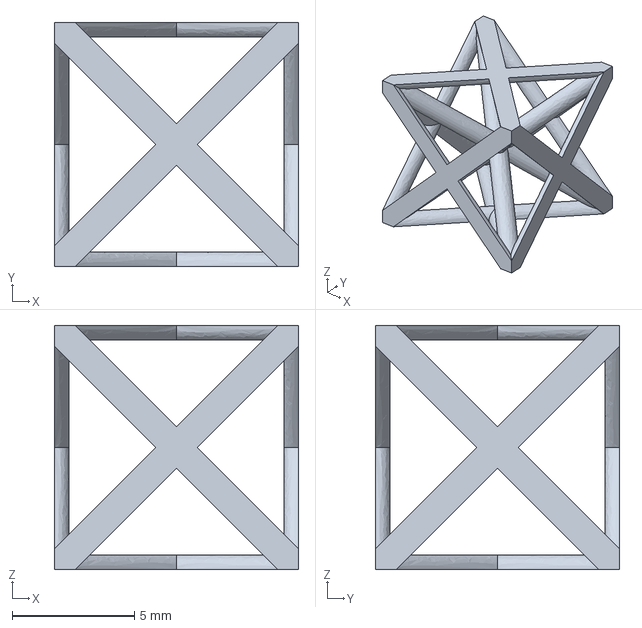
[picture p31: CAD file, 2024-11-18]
Unitcell/BC star tetrahedron/star tetrahedral new.igs
10.0 x 10.0 x 10.0 mm

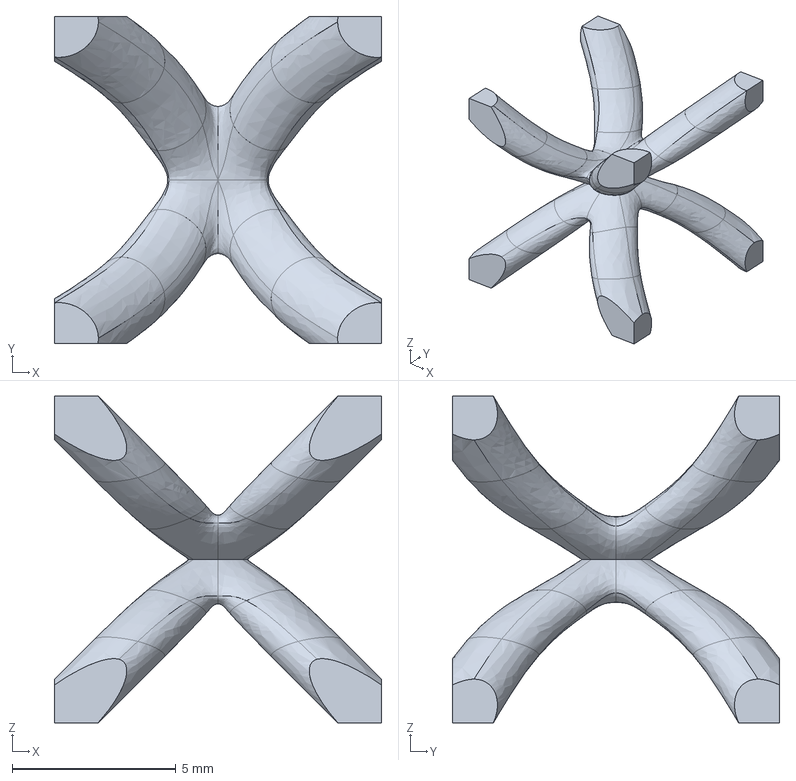
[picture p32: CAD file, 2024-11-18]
Unitcell/Bezier curve/bezier curve R 1.2 new.igs
10.0 x 10.0 x 10.0 mm

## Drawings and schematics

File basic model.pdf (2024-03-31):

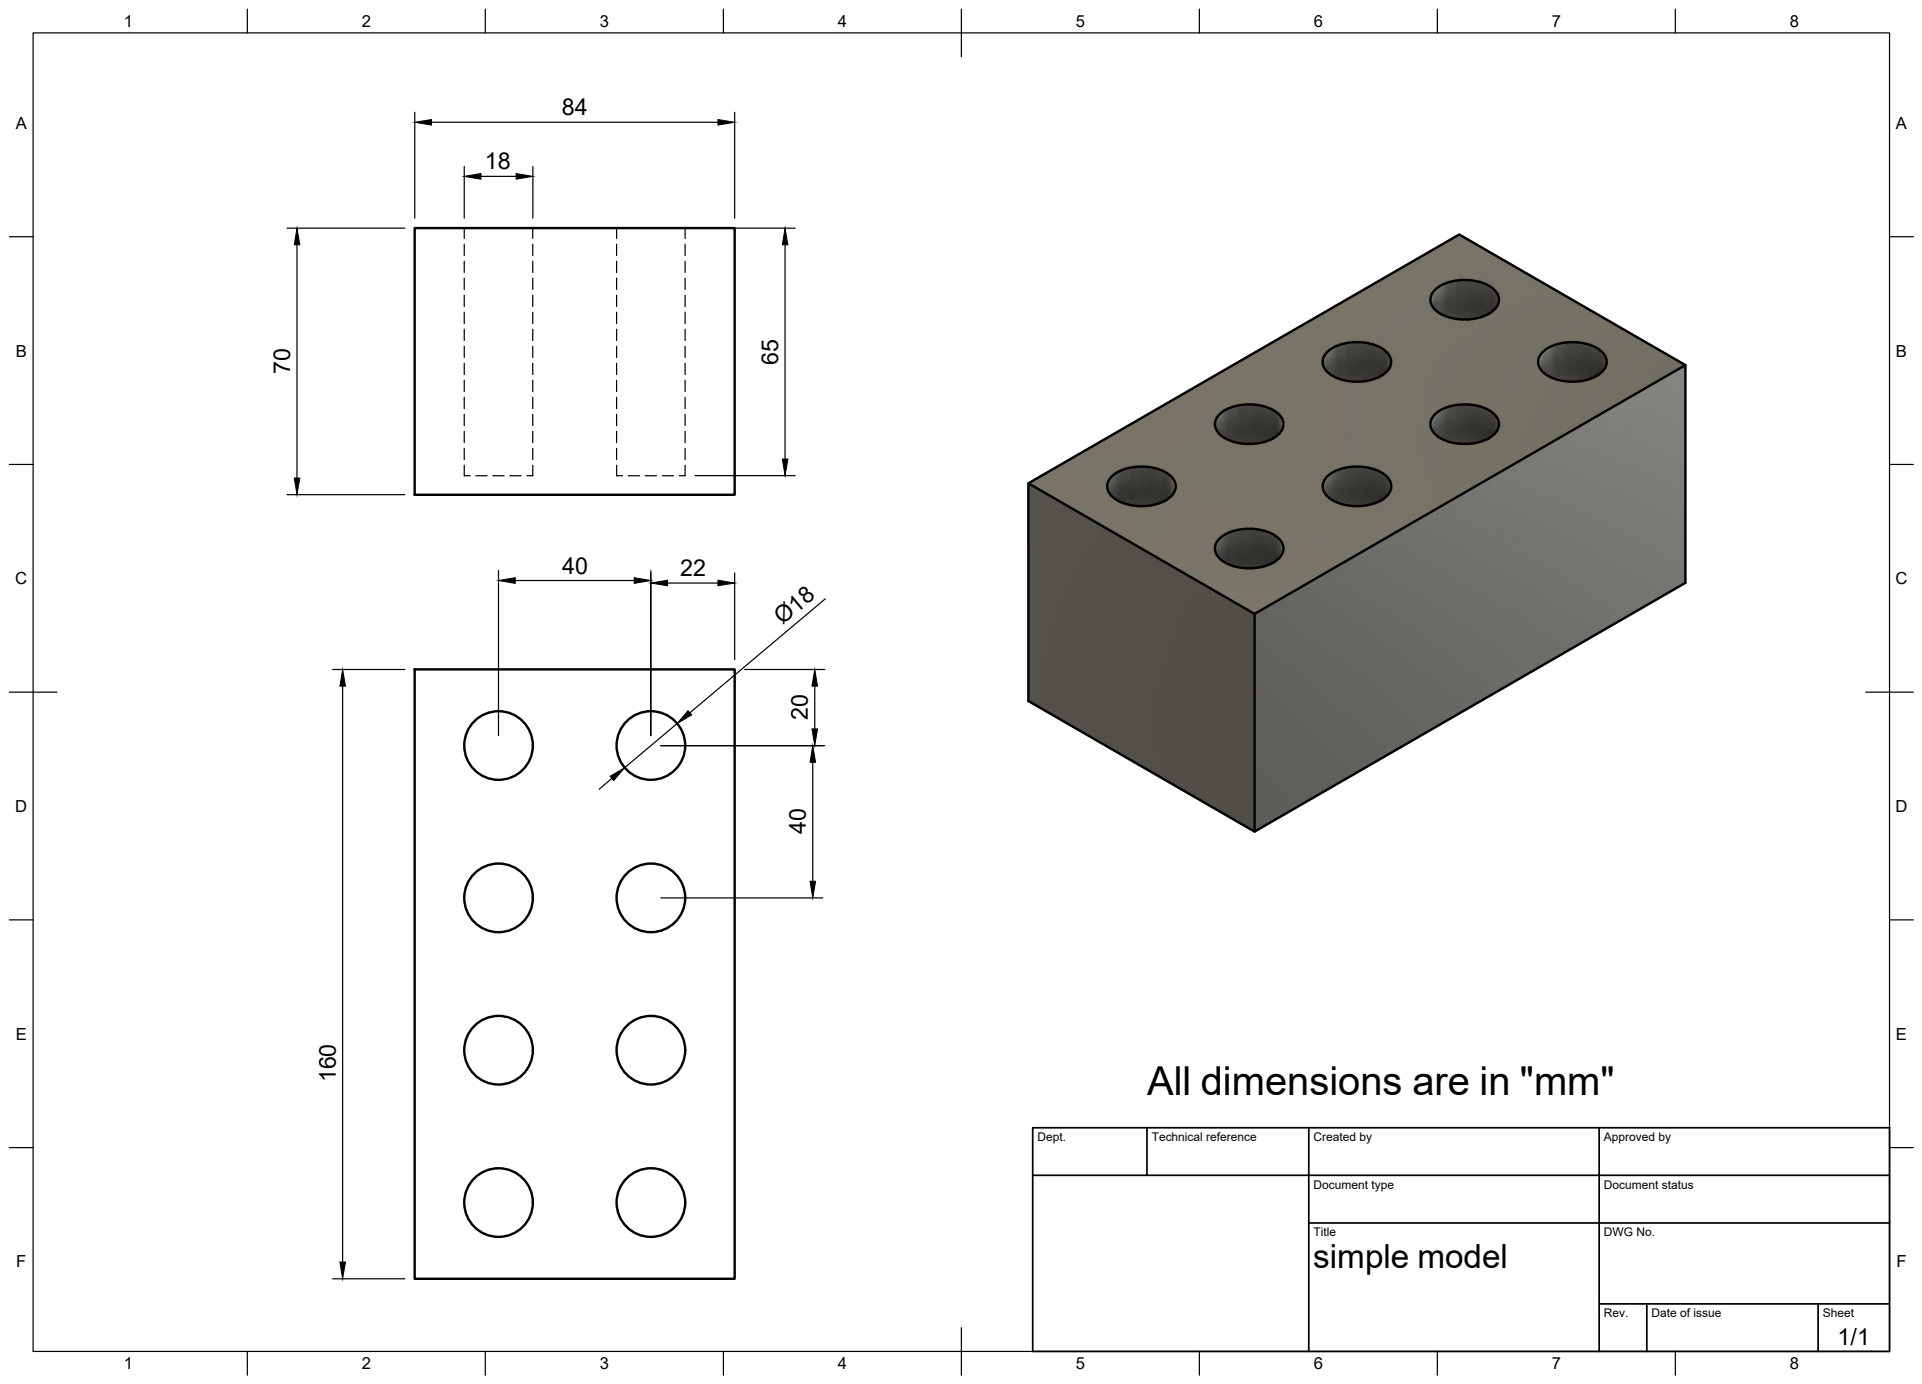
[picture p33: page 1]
Title; DWG No.; Rev.; Date of issue; Sheet; simple model

All dimensions are in "mm"

Dept. | Technical reference | Created by | Approved by

Document type | Document status

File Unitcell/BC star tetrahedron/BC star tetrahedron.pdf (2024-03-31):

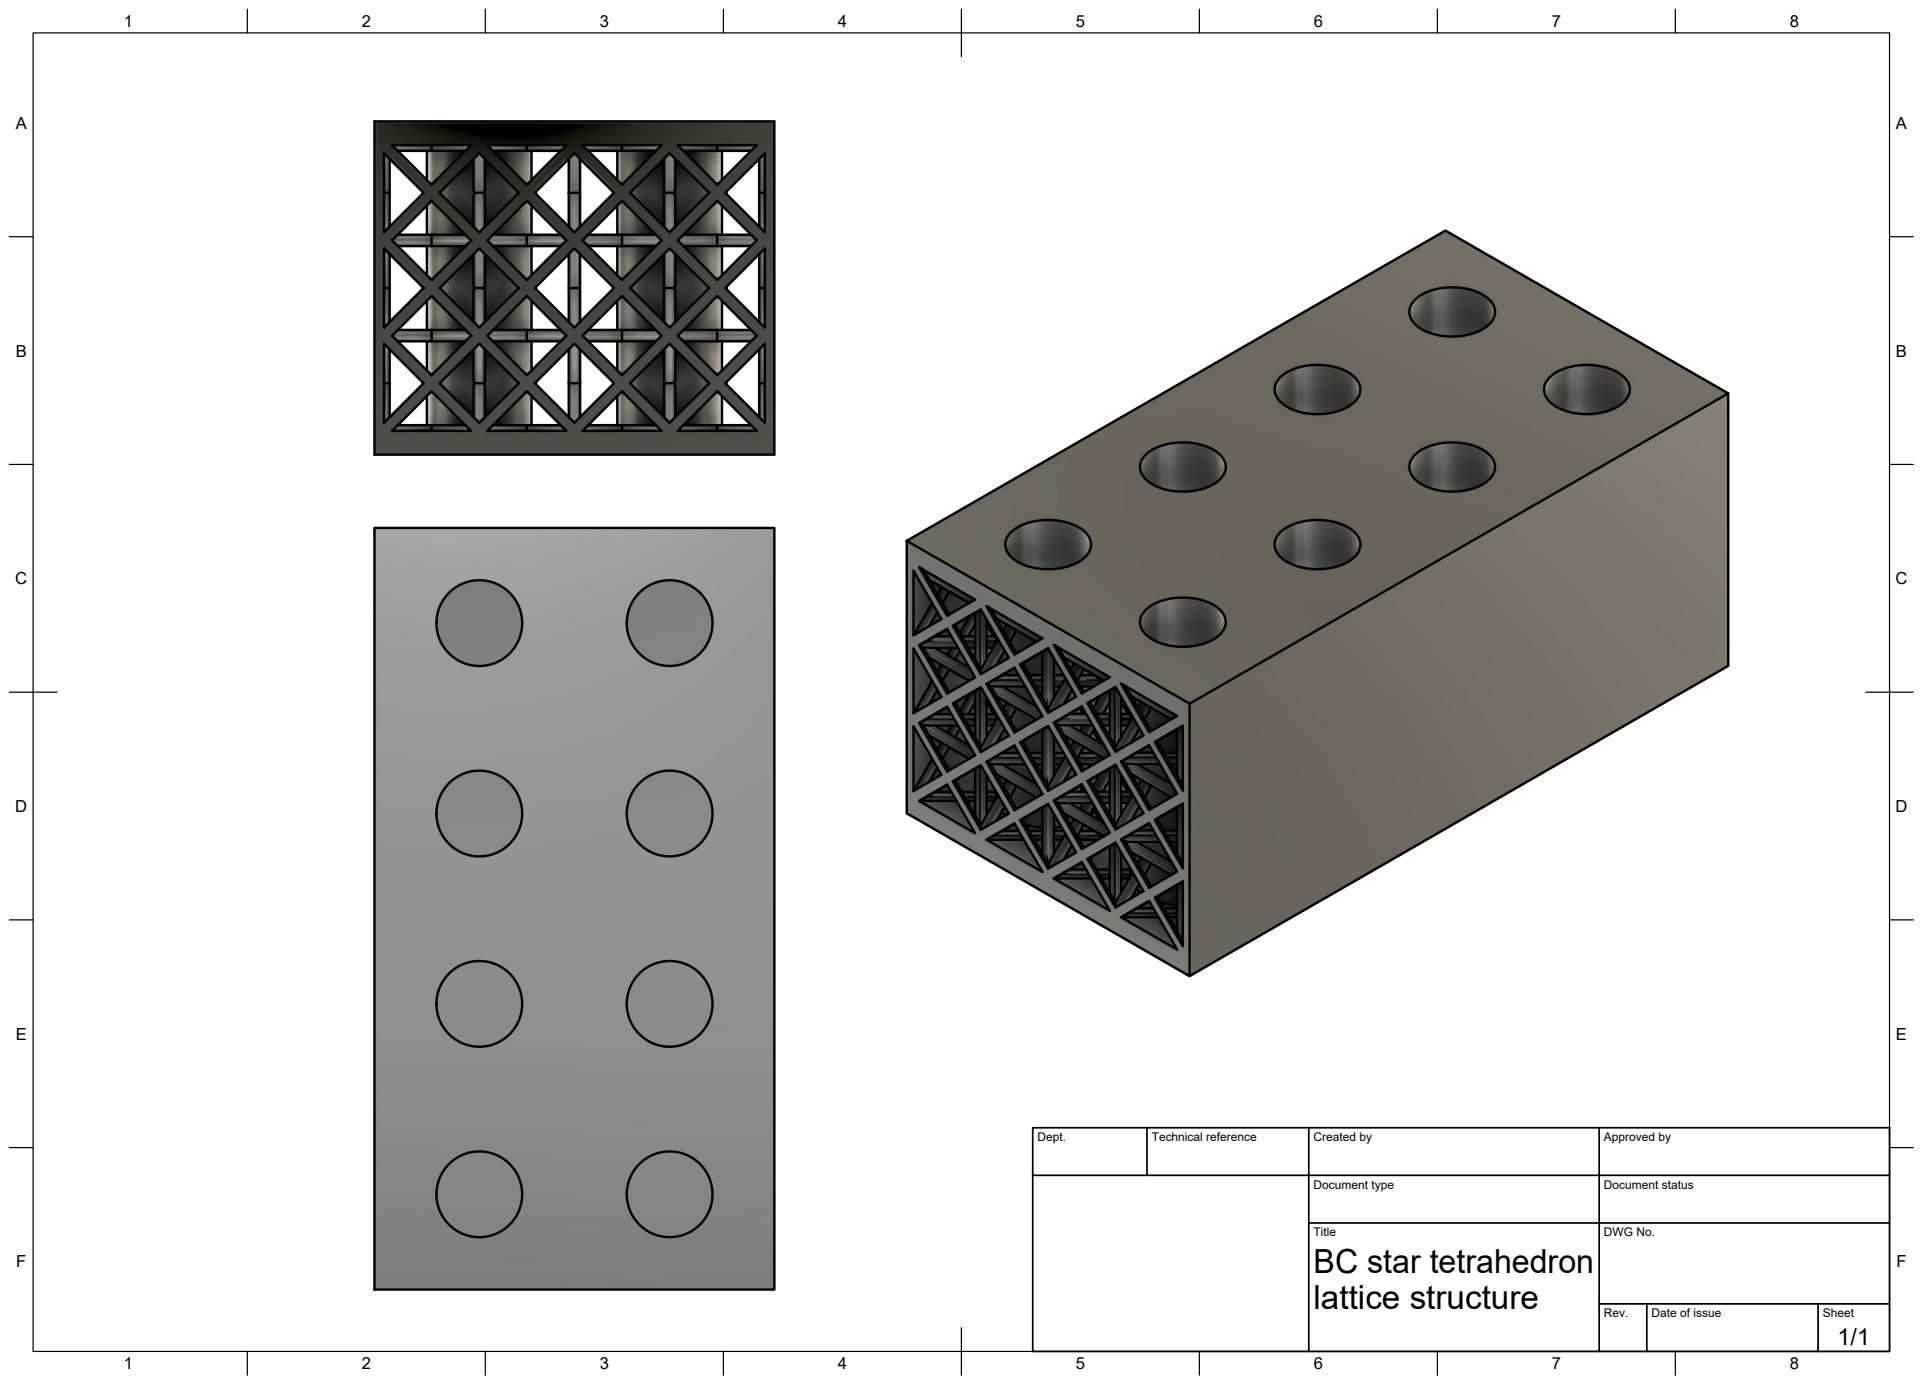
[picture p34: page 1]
Title; DWG No.; Rev.; Date of issue; Sheet

Dept. | Technical reference | Created by | Approved by

Document type | Document status

BC star tetrahedron
lattice structure
